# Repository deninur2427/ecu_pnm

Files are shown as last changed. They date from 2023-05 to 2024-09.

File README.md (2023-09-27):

# PNM Engine Control Planning

Custom Engine Control Unit for LPG

## Planning

- [X] Ngobrol Rencana

### Input

- [ ] Crankshaft Position Sensor
    - [ ] Pasang Gigi. Rencana Penempatan 12-1 Crank Tooth:
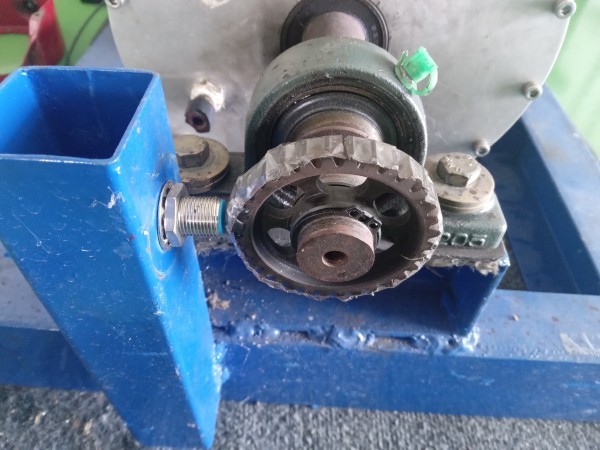
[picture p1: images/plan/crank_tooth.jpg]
images

    - [ ] Cetak Crank Teeth 12-1. Diameter Poros 22mm. Contoh:

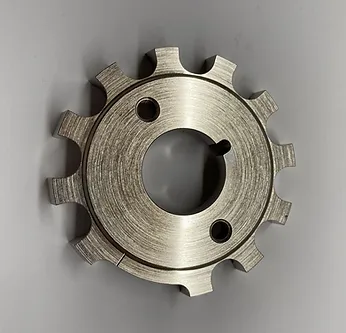
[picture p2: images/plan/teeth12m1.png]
images
    
    - [ ] Alternatif akrilik. Desain (tebal 2mm atau 3mm) untuk 24-1:

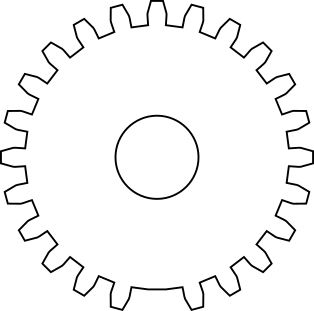
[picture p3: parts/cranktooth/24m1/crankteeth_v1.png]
    
    - [ ] Pasang Sensor Gigi. Rencana Sensor: Opto Interruptor: [Tokopedia](https://www.tokopedia.com/xurve-store/fc-03-ir-infrared-speed-kecepatan-sensor-photo-opto-interruptor)

- [ ] Trottle Position Sensor
    - [ ] Pemasangan. Dimana dekat mesin karena tidak terkoneksi dengan mekanik intake
    - [ ] Pembelian Sensor TPS: [Tokopedia](https://www.tokopedia.com/primacave/terbaru-sensor-tps-throttle-position-sensor-beat-fi-vario-125-thalland)

- [ ] Optimasi
    - [ ] Sensor Temperature (Tentative)
    - [ ] CO2 Sensor. Rencana [Tokopedia](https://www.tokopedia.com/amanahotopart/sensor-oxygen-honda-jazz-city-belakang-oksigen-co2-o2-copotan-asli-ori)

### Output

- [ ] Intake
    - [ ] Injector. Rencana [Tokopedia](https://www.tokopedia.com/sumahonda/injector-assy-fuel-pcx-150-k97-vario-150-esp-16450k59a11)
    - [ ] Pemasangan depan Inlet tanpa klep pengatur udara:
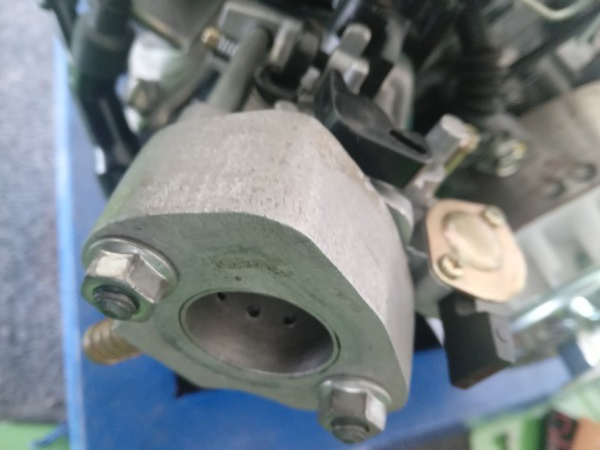
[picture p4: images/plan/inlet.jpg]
images


- [ ] Spark Plug
    - [ ] Coil. Rencana [Tokopedia](https://www.tokopedia.com/lestarimotor2/coil-koil-scoopy-esp-scoopy-fi-injeksi-30510-k16-a01-asli-ahm)
    - [ ] Cop Busi [Tokopedia](https://www.tokopedia.com/azkamotor99/canglong-tutup-cop-busi-grand-supra-x-x-125-legenda-revo-kharisma)
    - [ ] Plug telah tersedia
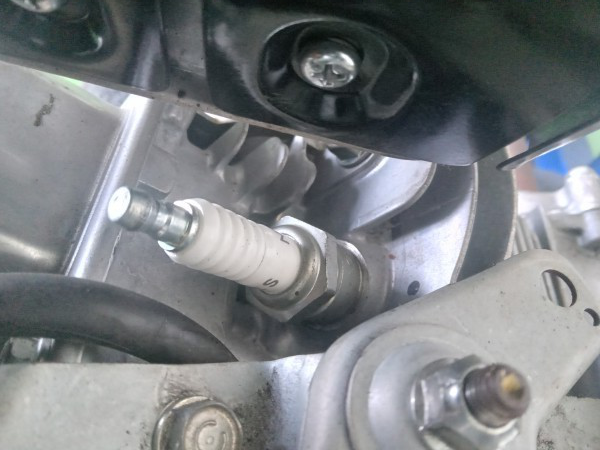
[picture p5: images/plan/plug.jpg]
images


- [ ] Aki. Alternator dan Kiprok tidak ada di Mesin
    - [x] Charger Aki tersedia
    - [ ] Jepit Aki dan Wiring nya

### PCB

- [ ] Drafting
    - [ ] Single Cylinder
        - [ ] Standalone PCB
        - [x] Nucleo Based
            - [x] F103RB
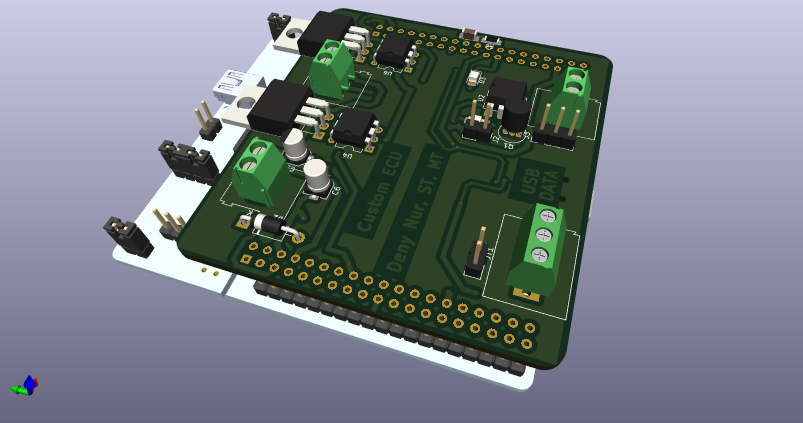
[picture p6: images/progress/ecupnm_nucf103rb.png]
images

- [x] Rencana Anggaran Total

### Update Kegiatan

- Tanggal 31 Juli 2023: [Catatan](https://github.com/deninur2427/ecu_pnm/blob/main/docs/notes/tes_31072023.md)
- Tanggal 24 Agustus 2023: [Catatan](https://github.com/deninur2427/ecu_pnm/blob/main/docs/notes/tes_24082023.md)
- Tanggal 19 September 2023: [Catatan](https://github.com/deninur2427/ecu_pnm/blob/main/docs/notes/tes_19092023.md)

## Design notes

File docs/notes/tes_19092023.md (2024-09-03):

# Catatan Kegiatan 19 September 2023

## Progress Kegiatan

### Hasil

Beberapa hasil yg didapat:
- Mesin sempat idle dalam waktu singkat namun tidak lanjut
- Timing pembakaran stabil namun terkadang masih terlambat
- Tidak ada gejala knocking

Klik gambar ini untuk memulai video

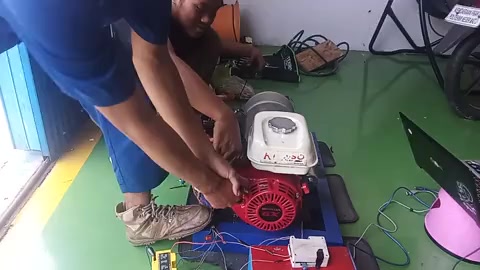
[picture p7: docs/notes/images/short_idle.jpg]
[](https://raw.githubusercontent.com/deninur2427/ecu_pnm/main/docs/notes/images/short_idle.mp4)

Perbaikan jaringan elektrikal dan koil ditukar.

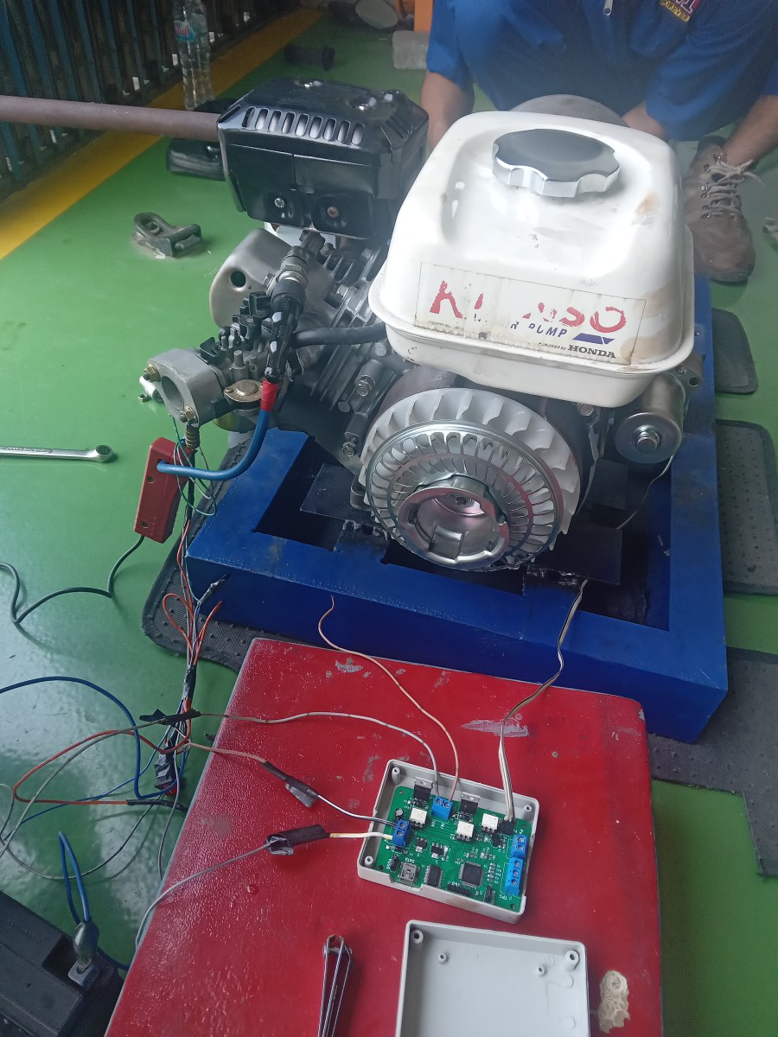
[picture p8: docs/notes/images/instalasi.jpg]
[]

### Catatan Perbaikan
- Pindah Crank-Teeth ke dekat block mesin untuk pembacaan lebih stabil

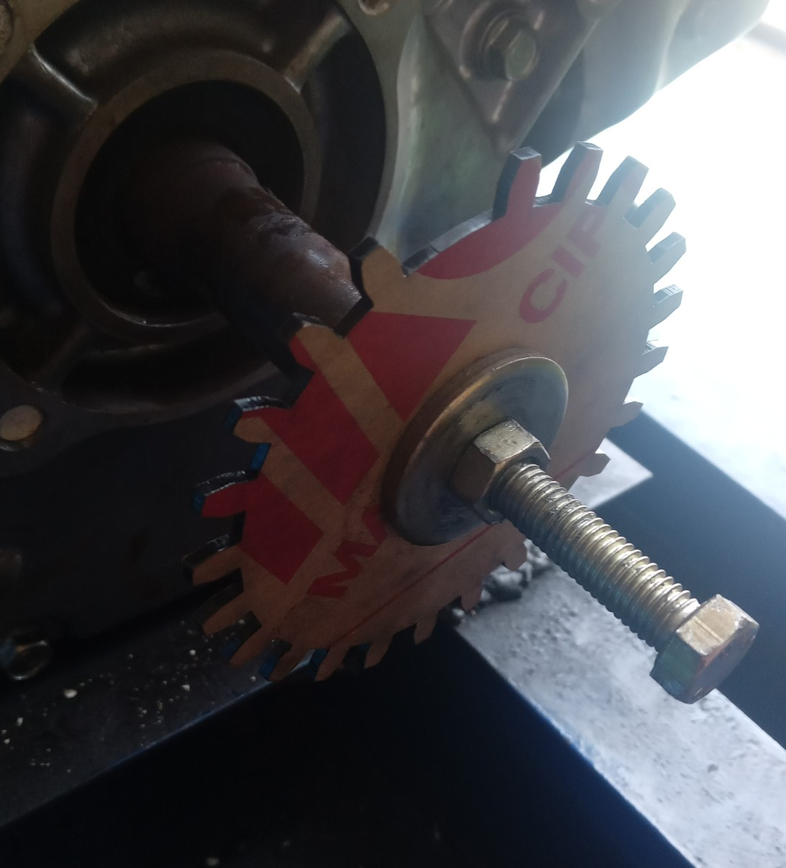
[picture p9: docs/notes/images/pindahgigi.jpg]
[]

- Update PCB sesuai catatan [berikut](https://github.com/deninur2427/ecu_pnm/blob/main/docs/notes/tes_24082023.md#update-pcb) dan mengecilkan ukuran

### Update PCB
- Regulator 5v ditambah opsi ke 7805
- Dioda FET pakai Schottky
- Dioda GND-GNDPWR pakai Schottky
- Serial-TTL ganti CH340C
- Wajib ada Capacitor Decouple dan Stabilizer
    + 100uF di 12V
    + 100uF di 5V
    + 100uF di 3v3
    + 0.1uF/100nF di 3v3 untuk Serial-TTL dan STM32

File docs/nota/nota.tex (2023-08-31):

\documentclass{article} % Definisi jenis dokumen

%%%%% Definisi paket-paket yang seharusnya digunakan %%%%%
\usepackage[utf8]{inputenc} % paket encoding input utf8
\usepackage[T1]{fontenc} % paket encoding huruf latin

%%%%% Definisi paket-paket yang digunakan sesuai kebutuhan %%%%%
\usepackage[yyyymmdd,hhmmss]{datetime} % paket tanggal-waktu
\usepackage{graphicx} % paket grafik/gambar
\usepackage[english]{babel} % paket modifikasi label/caption pada bahasa tertentu
\usepackage{geometry} % paket ukuran kertas dan margin
\usepackage{tabularray}
\usepackage{hyperref}
\usepackage{float}
\usepackage{caption}

%%%%% Pengaturan ukuran kertas dan margin %%%%%
\geometry{
	a4paper,
	left=10mm,
	right=10mm,
	top=15mm,
	bottom=15mm,
}

%%%%% Pengaturan perintah informasi perangkat lunak (hanya untuk GNU/Linux) %%%%%
\newcommand{\ShowOsVersion}{
	\immediate\write18{\unexpanded{foo=`uname -sro` && echo "${foo}" > tmp.tex}}
	\input{tmp}\immediate\write18{rm tmp.tex}
}

\newcommand{\ShowTexVersion}{
	\immediate\write18{\unexpanded{foo=`pdflatex -version | head -n1 | cut -d' ' -f1,2` && echo "${foo}" > tmp.tex}}
	\input{tmp}\immediate\write18{rm tmp.tex}
}

\begin{document}
%%%%%%%%%%%%%%%%%%%%%%%%%%%%%%%%%%%%%%%%%%%%%%%%%%%%%%%%%%%%%%%%%

	\begin{titlepage}

		\centering % untuk membuat tengah teks

		{
			\LARGE % pakai font besar
			\bf % pakai font BOLD
			Rekapitulasi Nota Kegiatan
		}

		\bigskip
		{\Large \bf Achmadi ST MT}
		\vfill % menambahkan ruang kosong vertikal

		\raggedright
		\noindent Buku ini ditulis dengan:\\ % tanda \\ menambahkan garis baru
		OS : \ShowOsVersion \\
		TeX : \ShowTexVersion \\
		Update: {\today} at \currenttime\\
	\end{titlepage}

	%%%%%%%%%%%%%%%%%%%%%%%%%%%%%%%%%%%%%%%%%%%%%%%%%%%%%%%%%%%%%%%%%

	\section{Tabel Rekapitulasi}
	
	\subsection{Transportasi}
	
	\begin{table}[H]
		\centering
		\begin{tabular}{|c|c|c|c|c|c|}
			\hline
			Items & Qty & Total & Shop & Paid & URL \\
			\hline
			Bus Kota & 6 & Rp. 30.000 & Bus-Suroboyo & Mas Deni & \hyperlink{https://tiketresmi.com/suroboyo-bus/}{Info-Traif} \\
			Bus Antar-Kota & 6 & Rp. 360.000 & Restu & 4/6 Mas Deni & - \\
			Penginapan & 1 & Rp. 150.000 & Red-Doorz & Mas Deni & - \\
			Penginapan & 1 & Rp. 198.000 & Red-Doorz & Mas Deni & - \\
			\hline
			\textbf{Total} & & Rp. 738.000 & - & - & - \\
			\hline
		\end{tabular}
	\end{table}

	\subsection{Prototype}

	\begin{table}[H]
	\centering
	\begin{tabular}{|c|c|c|c|c|c|}
		\hline
		Items & Qty & Total & Shop & Paid & URL \\
		\hline
		Opto-Encoder & 3 & Rp. 24.000 & Akhi-Shop Surabaya &  - & \hyperlink{https://www.tokopedia.com/akhishop/opto-coupler-encoder-sensor-module}{Tokopedia} \\
		Box-Plastic & 3 & Rp. 24.600 & Eltech Surabaya & - & \hyperlink{https://www.tokopedia.com/eltech-online/box-electronic-instrument-project-plastic-03-15-cream-40x84x142mm}{Tokopedia} \\
		Diode-Regulator & 12 & Rp. 5.100 & Mulsanne Surabaya & - & \hyperlink{https://www.tokopedia.com/mulsanne/ic-ams1117-5-volt-step-down-smd-800ma}{Tokopedia} \\
		Sabut Kawat & 1 & Rp. 7.200 & Alfamart Madiun & - & - \\
		Tang-Kabel, Komponen & - & Rp. 52.000 & Bintang-Mas Madiun & Mas Deni & - \\
		Komponen & - & Rp. 21.000 & Bintang-Mas Madiun & Mas Deni & - \\
		Komponen & - & Rp. 15.000 & Berkat Surabaya & - & - \\
		Komponen & - & Rp. 16.000 & Berkat Surabaya & - & - \\
		Komponen & - & Rp. 10.000 & Berkat Surabaya & - & - \\
		Komponen & - & Rp. 10.500 & Berkat Surabaya & - & - \\
		Komponen & - & Rp. 100.900 & Digiware Surabaya & - & \hyperlink{https://digiwarestore.com/id/}{Digiware} \\
		FT232RL & 2 & Rp. 102.100 & Digiware Surabaya & - & \hyperlink{https://digiwarestore.com/id/serial-communication/ft232rl-166019.html}{Digiware} \\
		Cap 0.1uF & 20 & Rp. 10.000 & Digiware Surabaya & - & \hyperlink{https://digiwarestore.com/id/smd-capacitor/01uf-50v-10-0805-t-241110.html}{Digiware} \\
		Potong Akrilik & 6 & Rp. 30.000 & Embong-Malang Surabaya & - & - \\
		PCB Versi 1 & 3 & Rp. 298.800 & Raftech & - & \hyperlink{https://www.tokopedia.com/raftech/jasa-cetak-pcb-double-layer-fr4-full-masking-jalur-masking-silkscreen}{Tokopedia} \\
		PCB Versi 2 & 3 & Rp. 371.300 & Gerai-Cerdas & - & \hyperlink{https://www.tokopedia.com/geraicerdas/cetak-pcb-1-keping-single-double-layer-rapid-prototyping-satuan}{Tokopedia} \\
		STM32F103RB & 4 & Rp. 180.000 & Shenzhen China & - & \hyperlink{https://id.aliexpress.com/item/1005002651134172.html}{Aliexpress} \\
		PCB Holder & 1 & Rp. 35.000 & Cellkit Surabaya & - & \hyperlink{https://www.tokopedia.com/cellkit/cellkit-penjepit-papan-pcb-single-per-pcb-holder}{Tokopedia} \\
		\hline
		\textbf{Total} & & Rp. 1.259.500 & - & - & - \\
		\hline
	\end{tabular}
	\end{table}

	\subsection{Konsumsi}
	
	\begin{table}[H]
		\centering
		\begin{tabular}{|c|c|c|c|c|c|}
			\hline
			Items & Qty & Total & Shop & Paid & URL \\
			\hline
			Roti Gembul & 2 & Rp. 37.000 & Gembul Madiun & Mas Deni & - \\
			Telur & 10 & Rp. 24.000 & Alfamart & - & - \\
			Telur & 6 & Rp. 21.000 & Alfmart & - & - \\
			\hline
			\textbf{Total} & & Rp. 82.000 & - & - & - \\
			\hline
		\end{tabular}
	\end{table}

	\newpage
	\section{Scan Nota}

	\begin{figure}[H]
		\centering
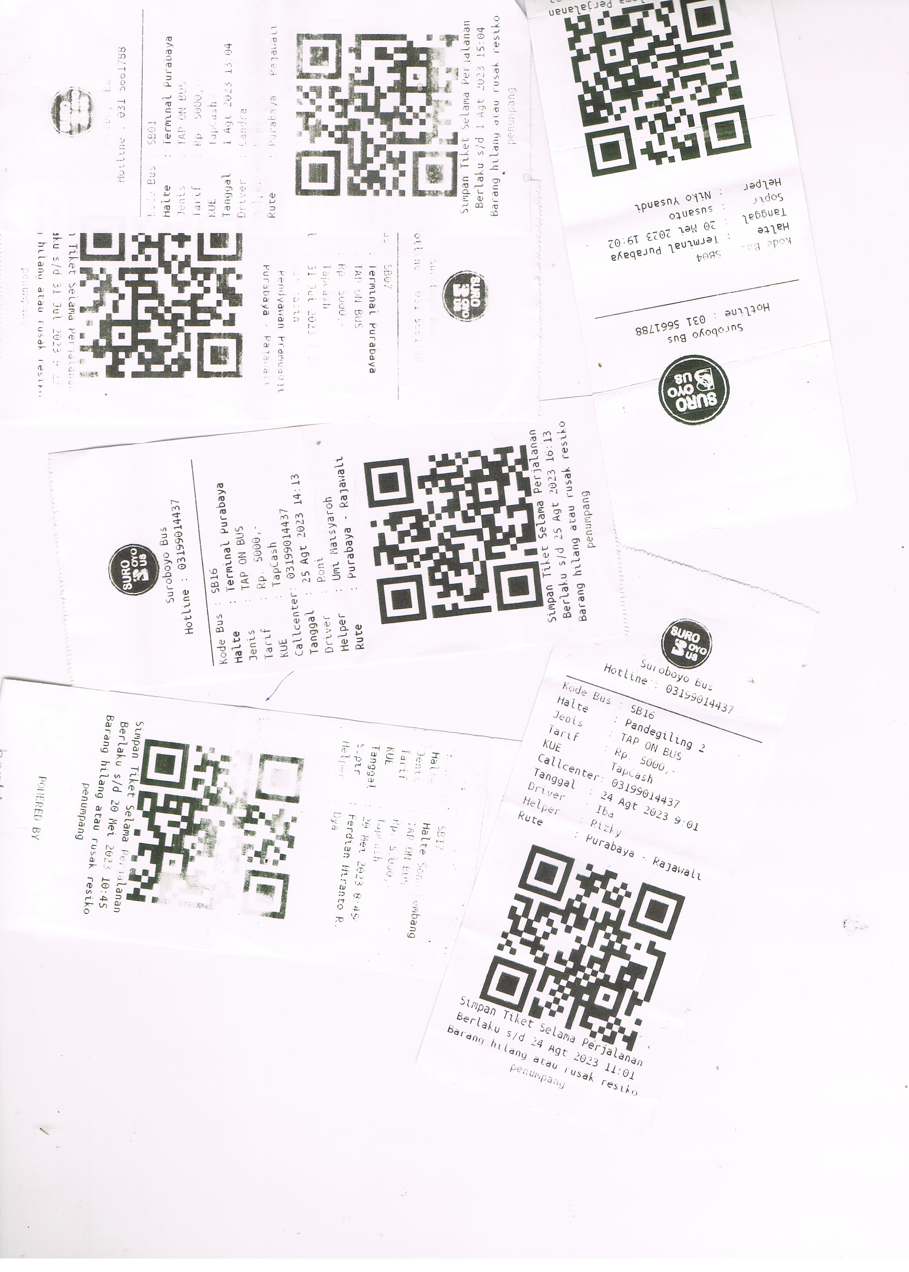
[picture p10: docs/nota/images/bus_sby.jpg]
		
	\end{figure}

	\begin{figure}[H]
		\centering
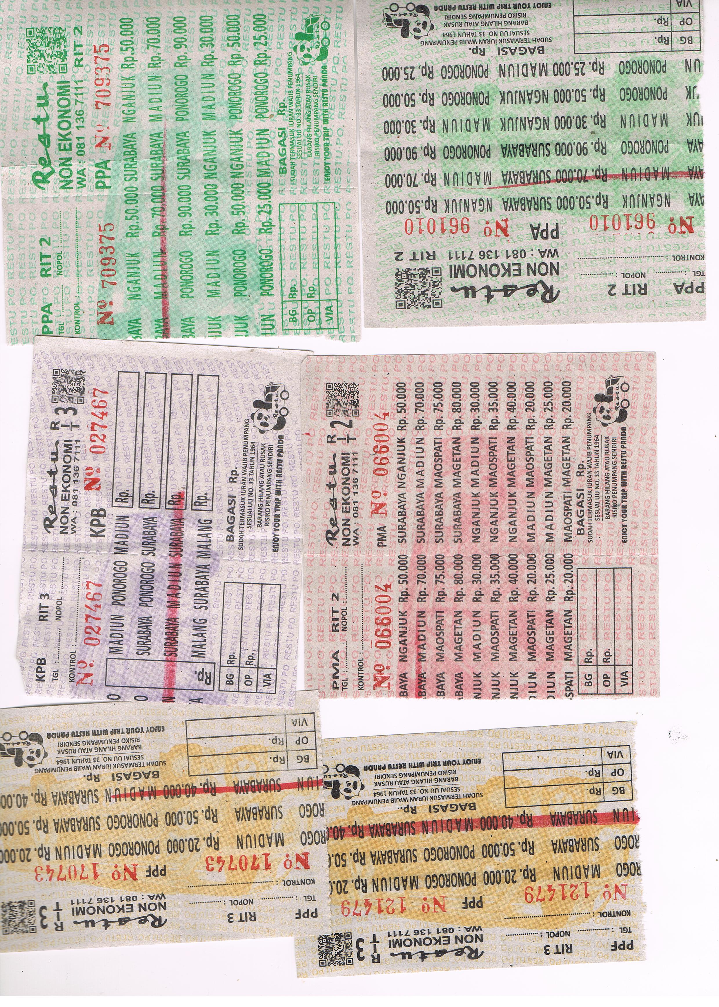
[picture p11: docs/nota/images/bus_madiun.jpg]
		
	\end{figure}

	\begin{figure}[H]
		\centering
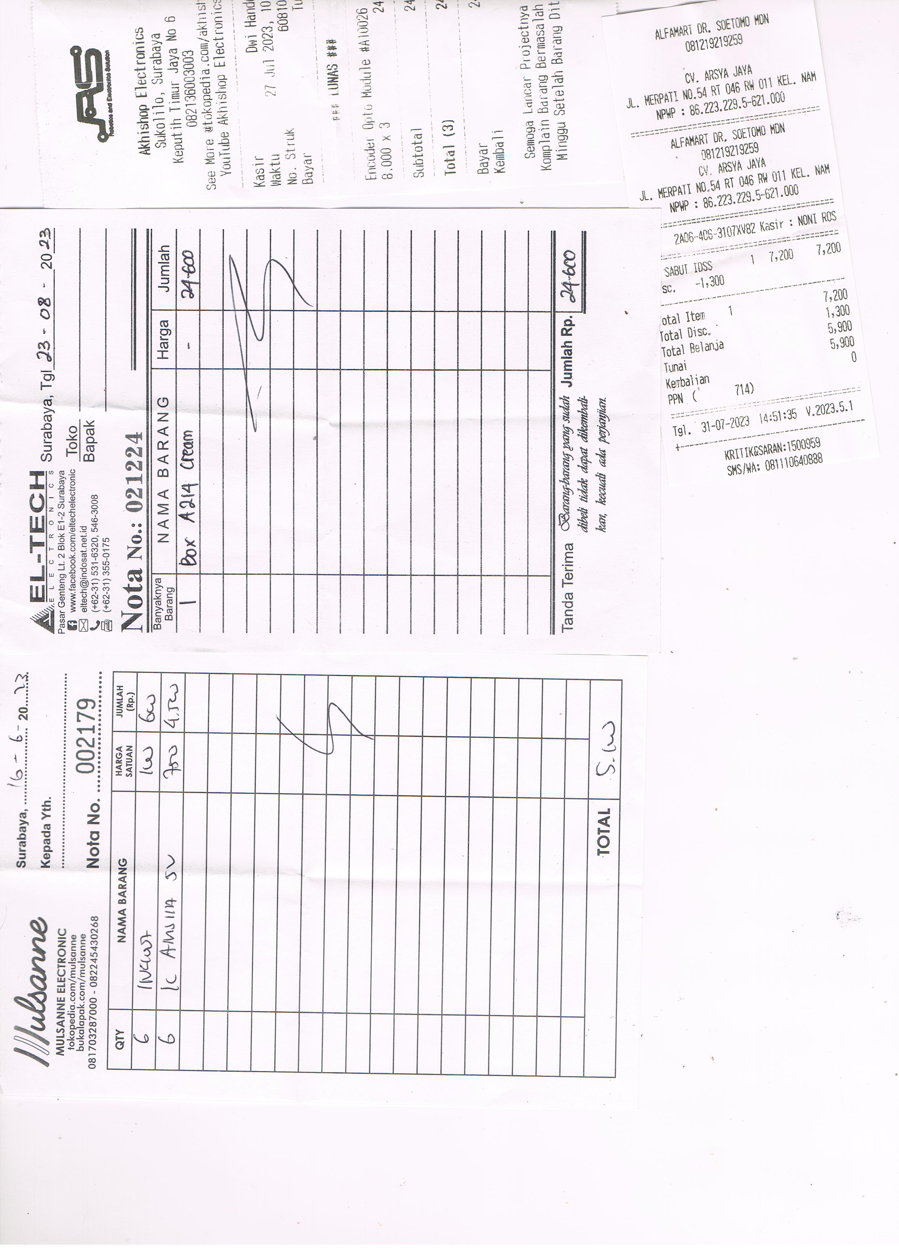
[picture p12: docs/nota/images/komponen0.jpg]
		
	\end{figure}

	\begin{figure}[H]
		\centering
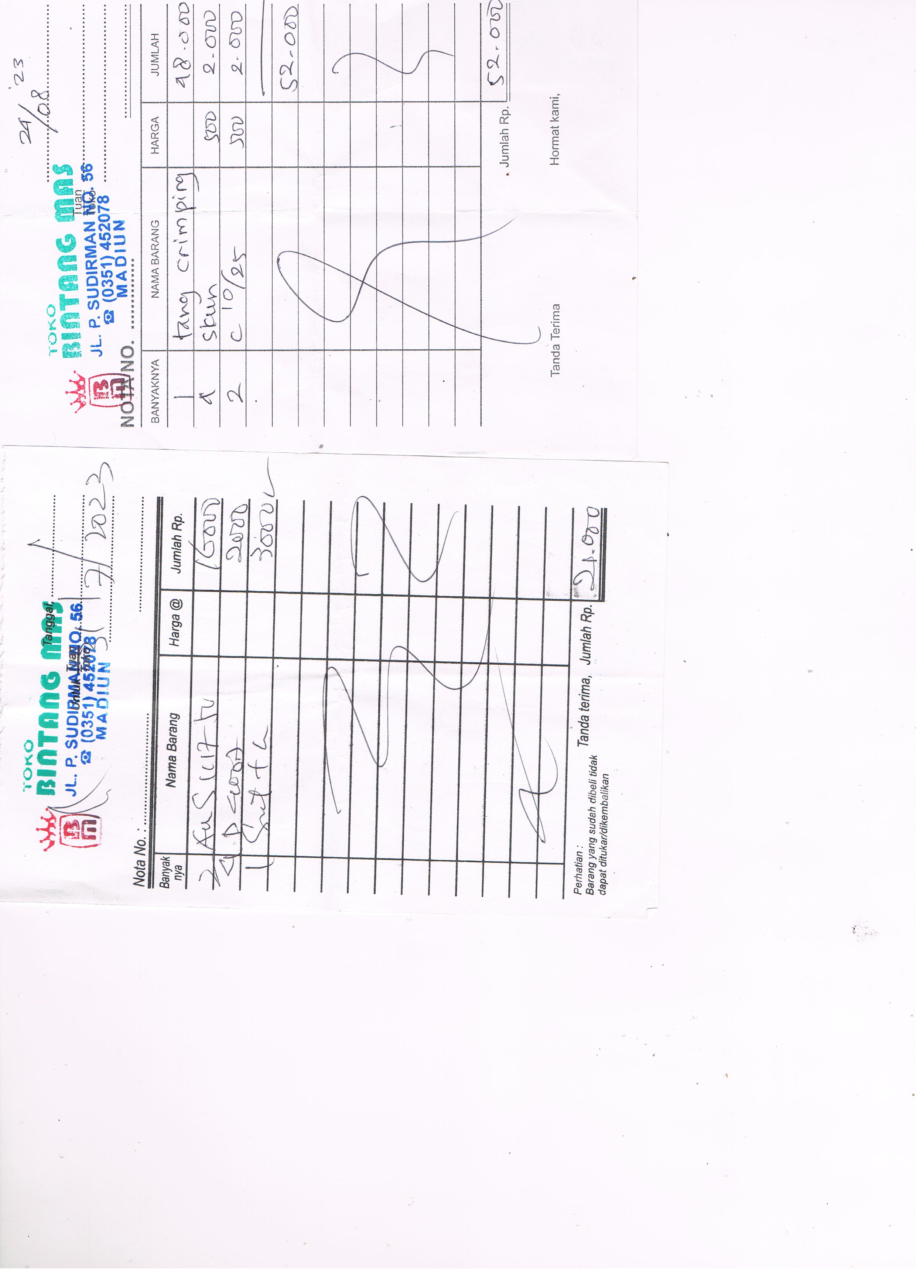
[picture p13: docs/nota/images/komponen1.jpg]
		
	\end{figure}

	\begin{figure}[H]
		\centering
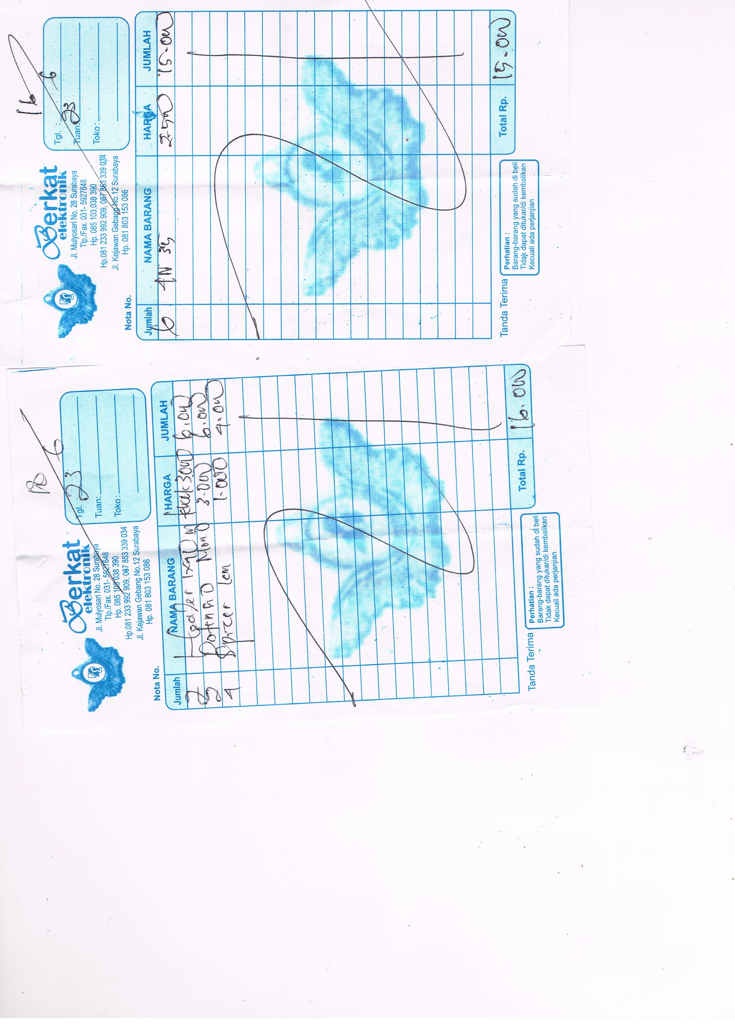
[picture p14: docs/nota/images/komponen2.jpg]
		
	\end{figure}

	\begin{figure}[H]
		\centering
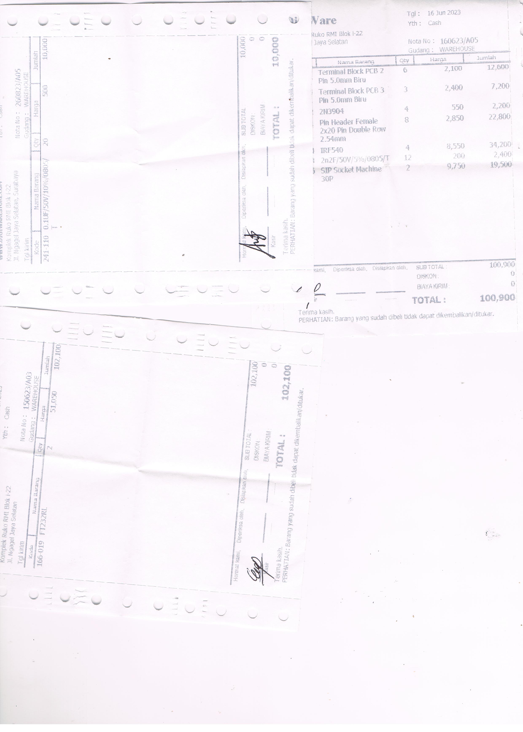
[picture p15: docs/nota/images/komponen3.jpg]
		
	\end{figure}

	\begin{figure}[H]
		\centering
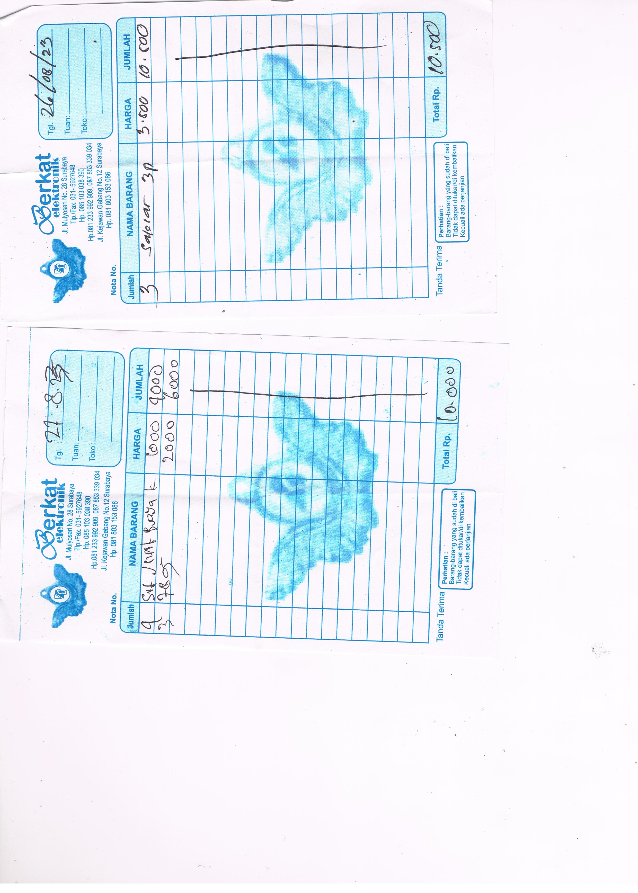
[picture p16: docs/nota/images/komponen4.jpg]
		
	\end{figure}

	\begin{figure}[H]
		\centering
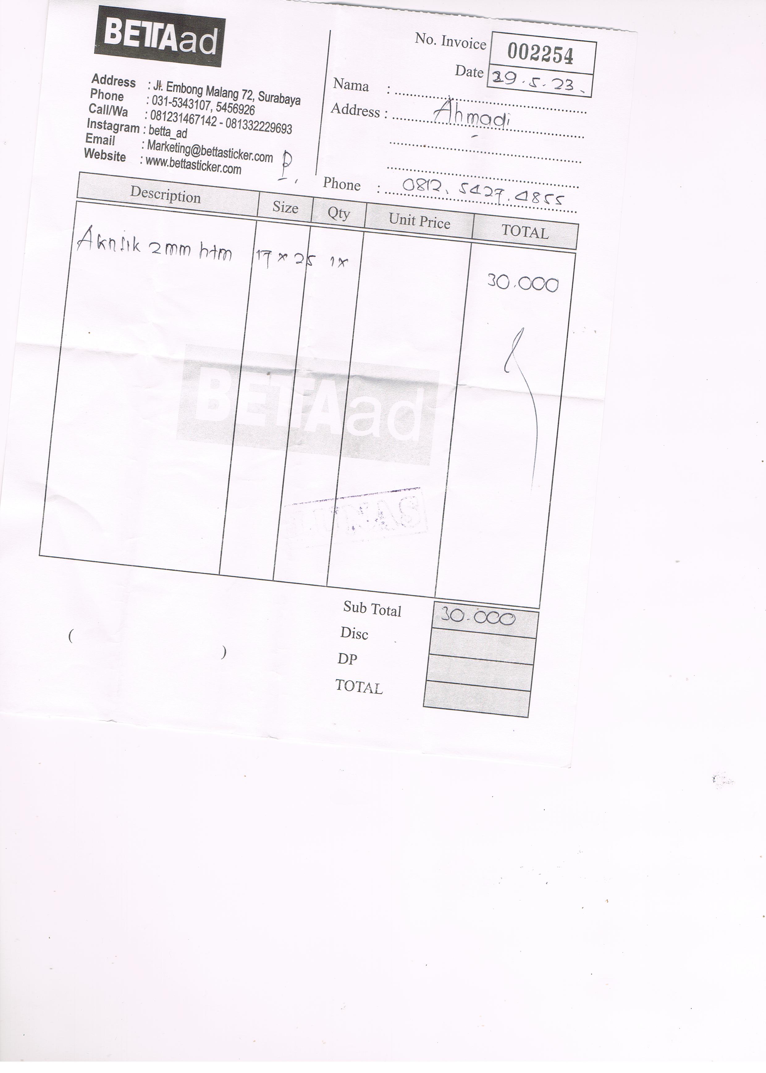
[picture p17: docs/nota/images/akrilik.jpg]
		
	\end{figure}

	\begin{figure}[H]
		\centering
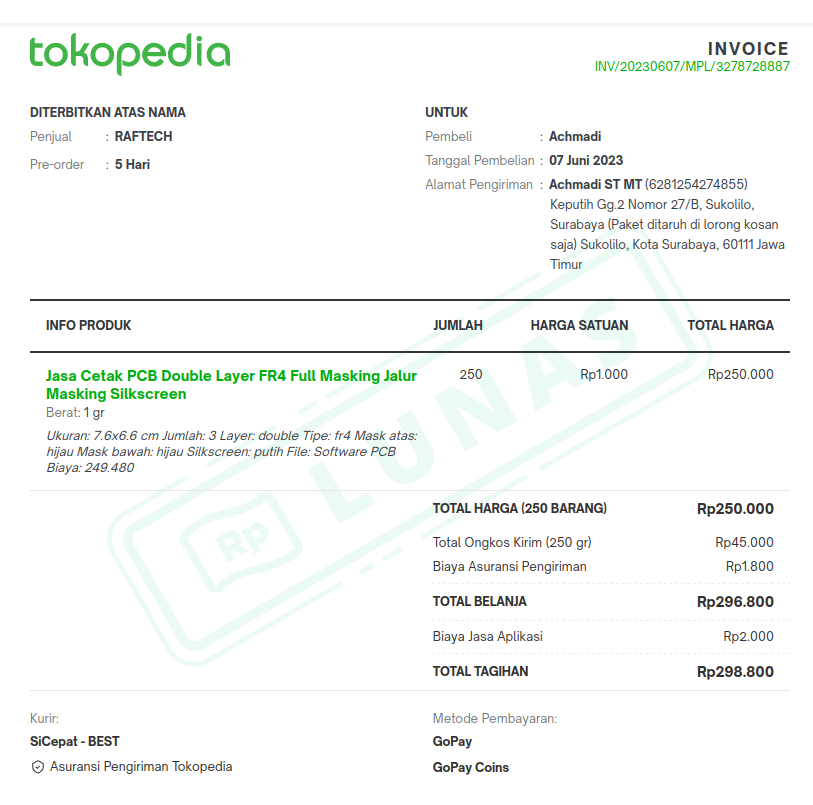
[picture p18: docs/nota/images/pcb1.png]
		
	\end{figure}

	\begin{figure}[H]
		\centering
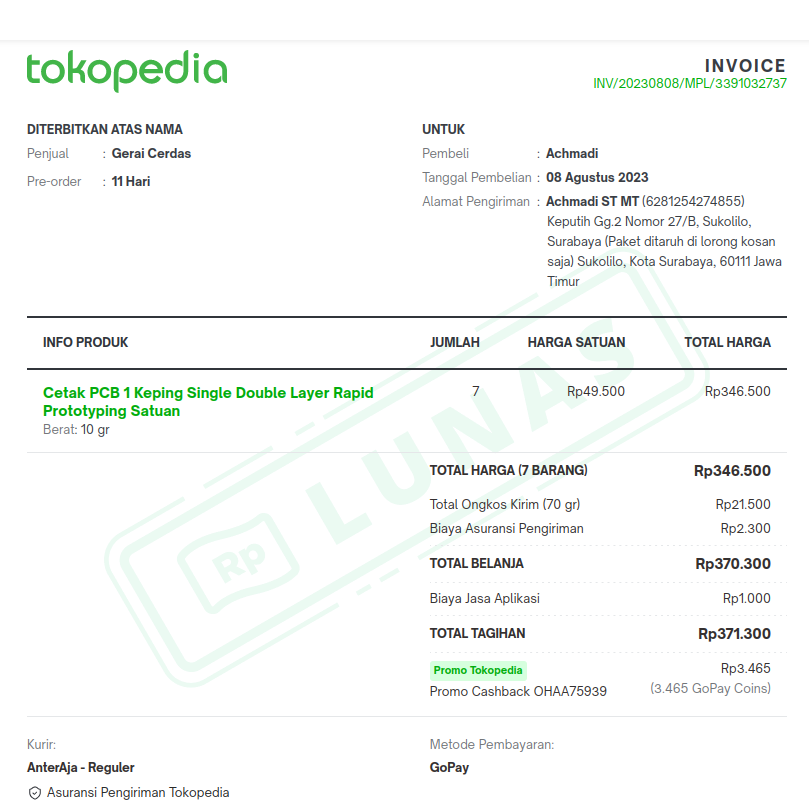
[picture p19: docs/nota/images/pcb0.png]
		
	\end{figure}
	
	\begin{figure}[H]
		\centering
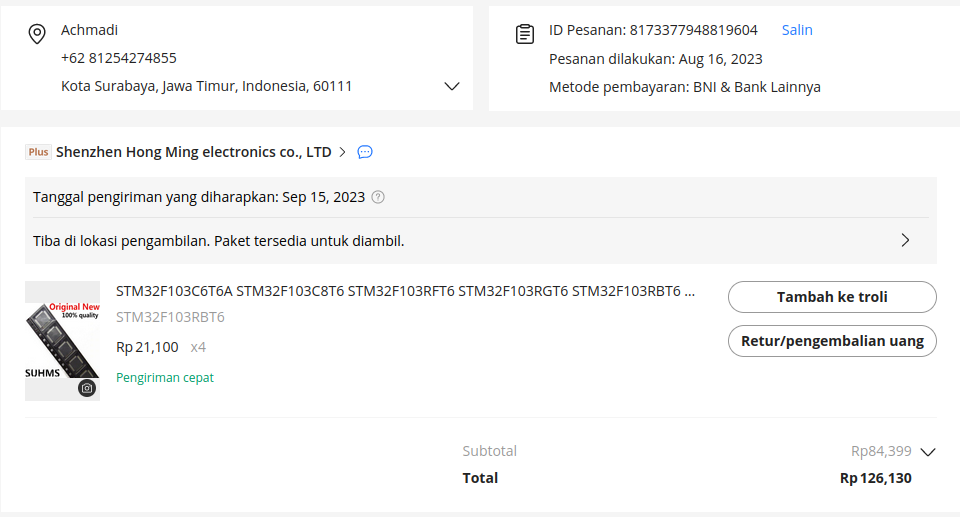
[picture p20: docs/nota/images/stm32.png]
		
	\end{figure}

	\begin{figure}[H]
		\centering
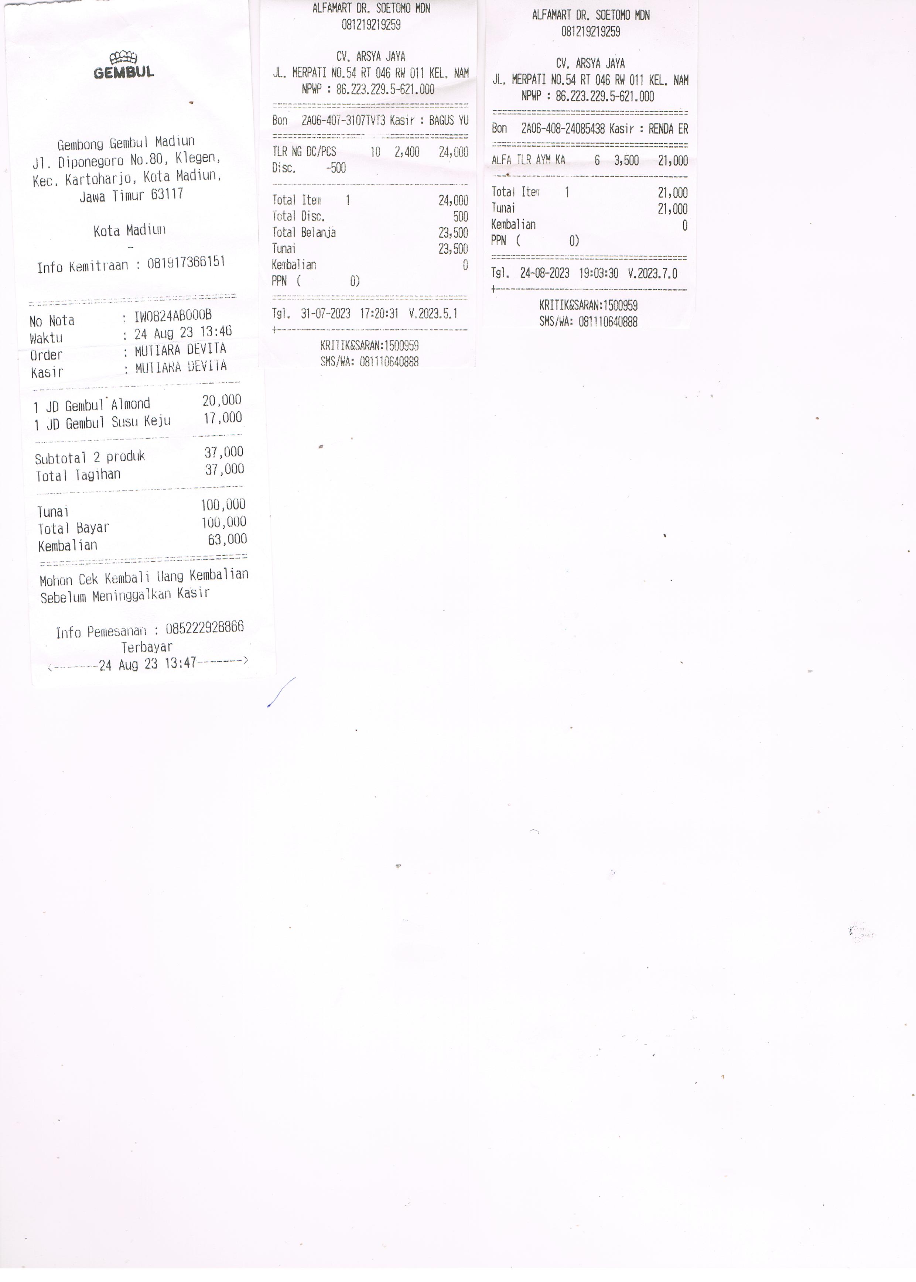
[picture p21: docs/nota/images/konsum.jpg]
		
	\end{figure}

	\begin{figure}[H]
		\centering
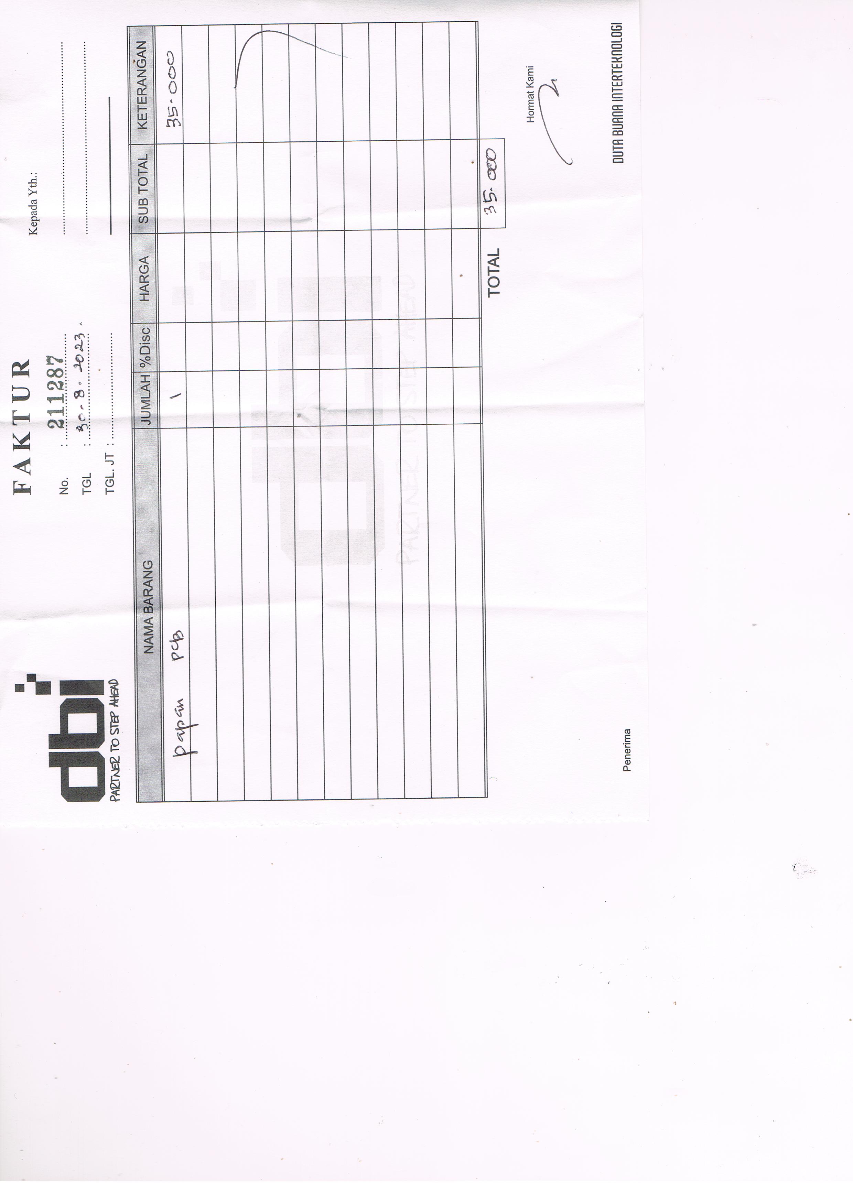
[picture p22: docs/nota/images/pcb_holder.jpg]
		
	\end{figure}

\end{document}

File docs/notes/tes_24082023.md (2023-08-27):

# Catatan Kegiatan 24 Agustus 2023

## Progress Kegiatan

### Perakitan

Merapikan wiring dan posisi coil

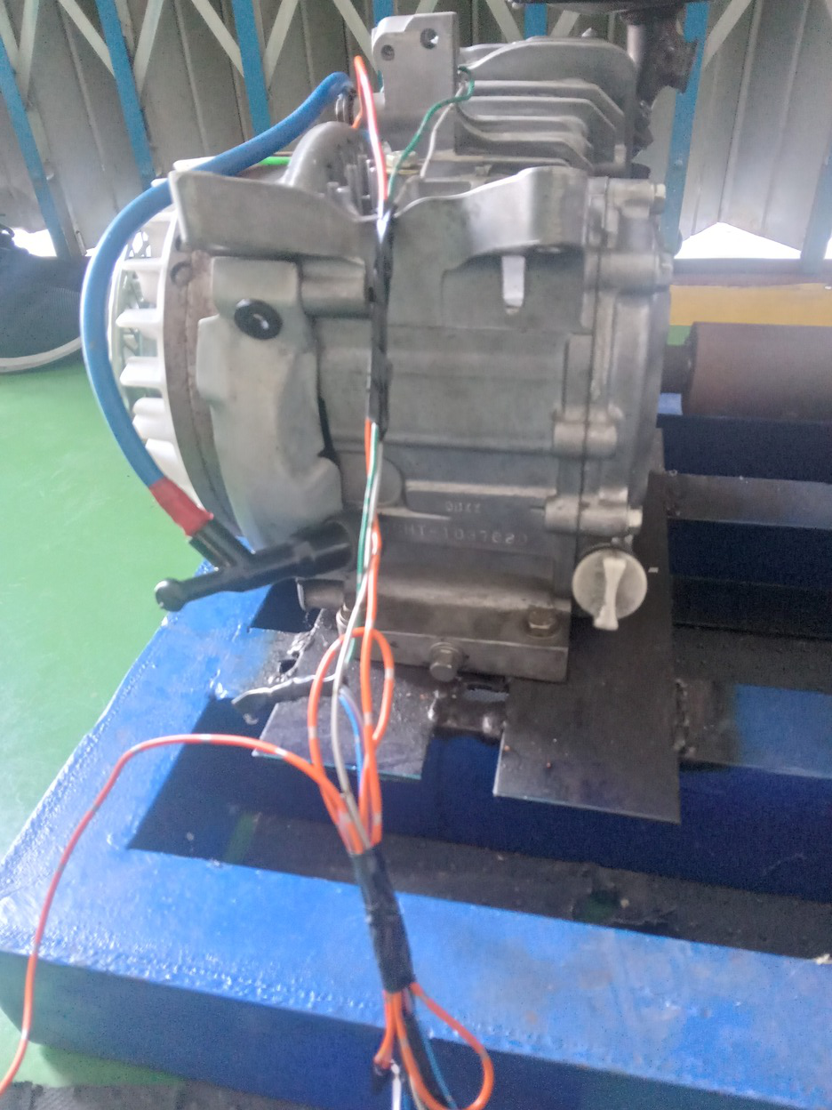
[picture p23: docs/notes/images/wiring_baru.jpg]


Kemudian instal prototipe ECU baru

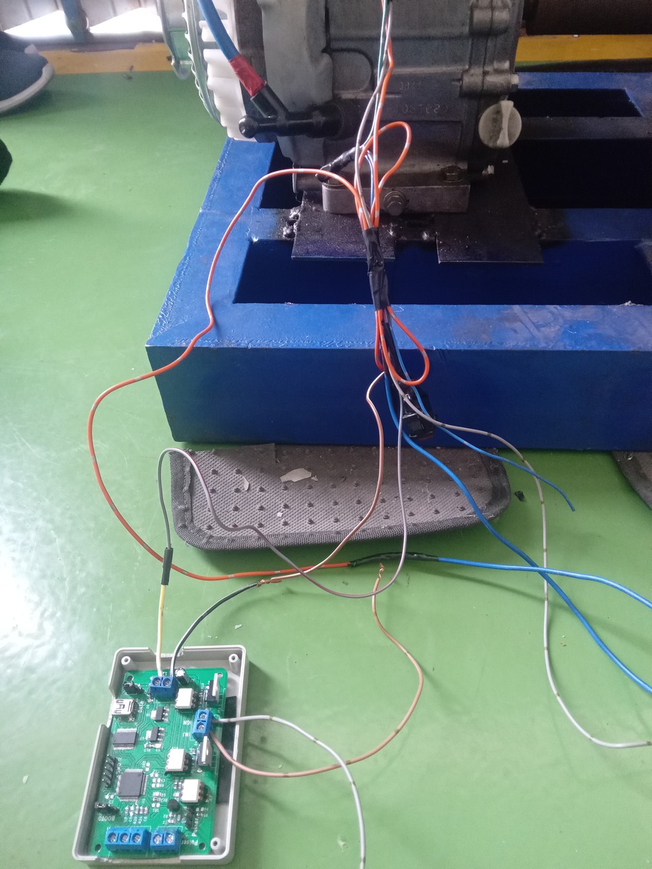
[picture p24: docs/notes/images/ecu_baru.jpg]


### Kendala

#### Coil Unstable

Coil memercik terus menerus.
Menyebabkan chip FTDI mati.

Dikurangi menggunakan Elco 10uF/25V

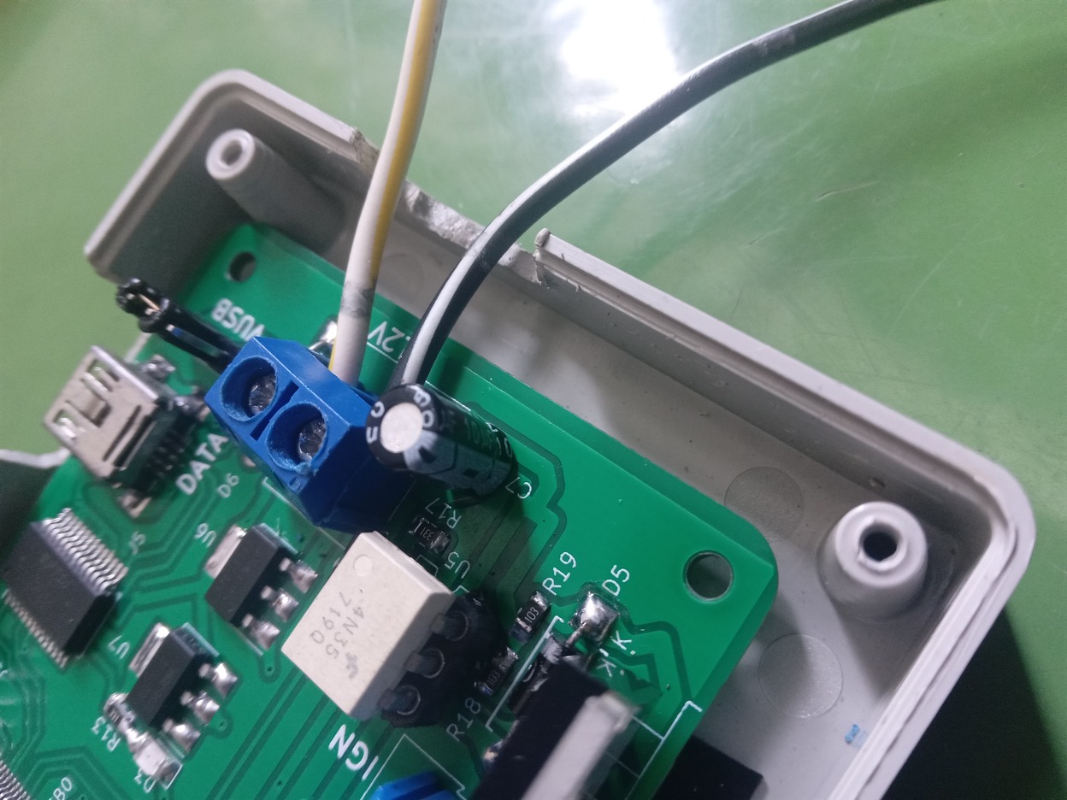
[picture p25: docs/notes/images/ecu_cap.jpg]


#### Engine Unstarted

Engine masih knocking

## Improvisasi

### Metode Tes

Pakai Ignition Timing Light Test

### Update PCB
- Regulator 5v ditambah opsi ke 7805
- Serial-TTL ganti CH340C
- Wajib ada Capacitor Decouple dan Stabilizer
    + 100uF di 12V
    + 0.1uF/100nF di 3v3 untuk Serial-TTL dan STM32

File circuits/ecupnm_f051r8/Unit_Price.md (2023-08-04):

# Local Indonesia Price Unit

| Komponen | QTY x Satuan | URL | Catatan |
|:---:|:---:|:---:|:---:|
| IC 4N35 | Rp. 10.000 | [Tokopedia](https://www.tokopedia.com/jevonelektronik/ic-4n35-optocoupler-original) | - |
| STM32F051R8T6 | Rp. 80.000 | [Aliexpress](https://id.aliexpress.com/item/1005004923074652.html) | Masih Stock |
| AMS1117 5v | Rp. 2.000 | [Tokopedia](https://www.tokopedia.com/cosmic-iot/ams1117-5v-ams-1117-5-volt-smd-sot-223-sot223) | - |
| AMS1117 3v | Rp. 2.000 | [Tokopedia](https://www.tokopedia.com/mri/ams1117-3-3v-smd-regulator-sot-223) | - |
| H11L1 | Rp. 7.000 | [Tokopedia](https://www.tokopedia.com/eltech-online/h11l1-h-11l1-h11-l1-optocoupler) | - |
| FT232RL | Rp. 65.000 | [Tokopedia](https://www.tokopedia.com/eltech-online/ft232rl-ft-232rl-232-ftdi-usb-to-serial-uart-rs-232-rs232-rs) | - |
| IRF540 | Rp. 22.000 | [Tokopedia](https://www.tokopedia.com/eltech-online/ft232rl-ft-232rl-232-ftdi-usb-to-serial-uart-rs-232-rs232-rs) | - |
| 2N3904 | Rp. 1.200 | [Tokopedia](https://www.tokopedia.com/isee/2n-3904-2n3904-dip-transistor-to-92-0-2a-40v) | - |
| PCB Prototyping | Rp. 150.000 | [Tokopedia](https://www.tokopedia.com/geraicerdas/cetak-pcb-1-keping-single-double-layer-rapid-prototyping-satuan) | Estimasi Total Luasan PCB |
| Non-IC | Rp. 50.000 | - | Gelondongan Komponen |
| Ongkir/Transport | Rp. 50.000 | - | - |
| Jasa Solder/Assembly Manual | Rp. 150.000 | - | Termasuk Checking PCB |

Total Estimasi Per Unit Rp. 587.200

Belum Termasuk:
- Jasa Programming Firmware
- Jasa Programming Interfacing

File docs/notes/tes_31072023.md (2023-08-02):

# Catatan Kegiatan 31 Juli 2023

## Progress Kegiatan

### Perakitan:

#### Encoder

PickUp encoder untuk posisi Crankshaft telah terpasang.

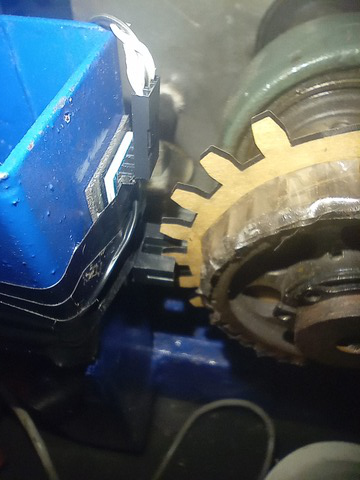
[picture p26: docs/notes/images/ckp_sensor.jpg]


**Catatan:** Perhitungan nomor gigi perlu dicek ulang

#### Wiring Coil

Konfigurasi Wiring:
- 0V di tulang coil
- Signal di pin dekat kabel busi
- 12V di pin yang tersisa
    
**Catatan:** Coil sudah dapat memantik
    
#### Wiring Injector

Konfigurasi Wiring:
- 12V di kabel merah
- Signal di kabel hitam
    
#### Wiring Overall

Dokumentasi hasil Wiring dan pemasangan Sakelar:

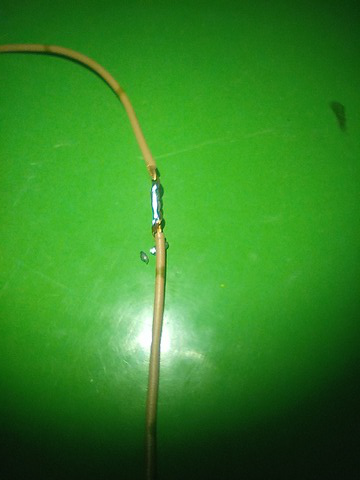
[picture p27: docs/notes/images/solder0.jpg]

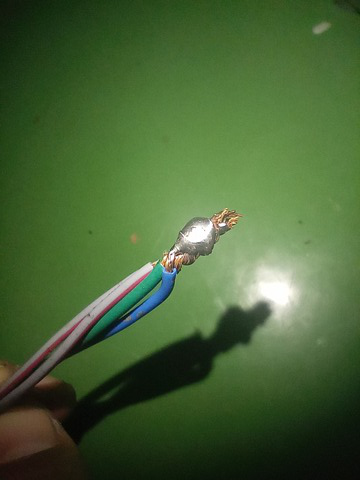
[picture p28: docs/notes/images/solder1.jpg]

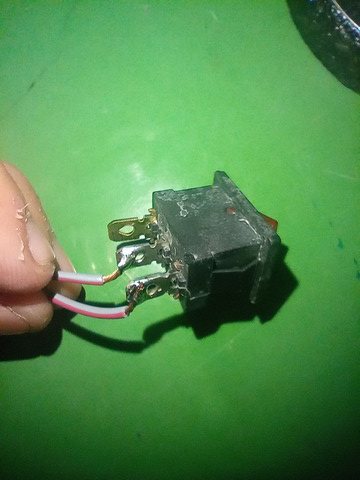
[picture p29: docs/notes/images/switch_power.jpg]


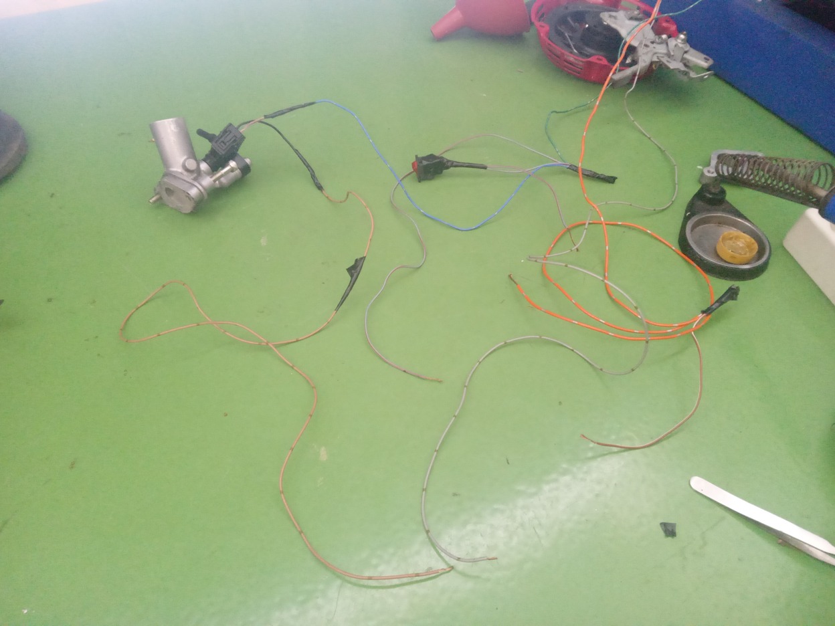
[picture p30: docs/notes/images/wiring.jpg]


### Masalah

Tegangan Induksi Balik dari Coil menyebabkan:

- Regulator 3.3 Volt terbakar:



- Chip STM32 mengalami kerusakan di internal flash memory sehingga ukuran memory mengecil dan tidak dapat "mass erase":





### Penanganan Masalah

- Pemasangan Diode Proteksi Induksi



- Ganti Chip STM32

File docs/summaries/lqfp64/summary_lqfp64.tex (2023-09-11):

\documentclass[a4paper,12pt,oneside,pdflatex,italian,final,twocolumn]{article}

\usepackage[utf8]{inputenc}
\usepackage{parallel}
\usepackage{siunitx}
\usepackage{booktabs}
\usepackage{fancyhdr}
\usepackage{subcaption}
\usepackage{minted}
\usepackage{hyperref}
\usepackage{pdfpages}

\usepackage[export]{adjustbox}
\usepackage[margin=0.5in]{geometry}
\addtolength{\topmargin}{0in}

\usepackage{libertine}
\renewcommand*\familydefault{\sfdefault}  %% Only if the base font of the document is to be sans serif
\usepackage[T1]{fontenc}

\hypersetup{
	colorlinks=true, %set true if you want colored links
	linktoc=all,     %set to all if you want both sections and subsections linked
	linkcolor=blue,  %choose some color if you want links to stand out
	urlcolor=blue,   %url color
}

\definecolor{LightGray}{gray}{0.95}

\title{Custom Single Cylinder ECU}
\author{Achmadi ST MT}
\date{September 2023}

\begin{document}
	\pagestyle{fancy}

	\lhead{DeniNur/Achmadi}
	\chead{\today}
	\rhead{Specification Document}

	\onecolumn
	\begin{figure}

	\end{figure}\begin{minipage}{0.47\textwidth}
		\centering

	\end{minipage}
	\hfill
	\begin{minipage}{0.47\textwidth}
		\raggedleft
		\Huge \textbf{Custom Single Cylinder ECU v1}
	\end{minipage}

	\begin{figure}
		\begin{minipage}{0.47\textwidth}

			\section{Overview}
			\begin{itemize}
				\item Minimal and Flexible Engine Control Unit
				\item Reading TPS and RPM with calibration capability
				\item Control Injection and Ignition
				\item Serial Data Interface in Real-time
				\item Designed to easy of use for general Injection engines
				\item Build as single circuit board with minimal setup
				\item Based on STM32Fx series that popular in automotive industries
			\end{itemize}

		\end{minipage}
		\hfill
		\begin{minipage}{0.47\textwidth}
			\centering
			
		\end{minipage}
	\end{figure}

	\raggedright

	\section{Repository URLs}

	\begin{itemize}
		\item PCB Design: \url{https://github.com/deninur2427/ecu_pnm/tree/main/circuits/ecupnm_f051r8}

		\item Firmware: \url{https://github.com/deninur2427/ecu_pnm/tree/main/firmware/}

		\item Interface: \url{https://github.com/deninur2427/ecu_pnm/tree/main/interface/ecu_view/}

		\item Overall Repository: \url{https://github.com/deninur2427/ecu_pnm/}
	\end{itemize}

	\section{Technical specification}
	\centering
	\begin{tabular}{lcr}
		\toprule
		Parts & Unit & Value \\
		\midrule
		Power voltage & $V$ & 12 \\
		Main Chip & & STM32Fx LQFP64 \\
		Storage & & Internal EEPROM \\
		USB  Data Interface & & USB-Serial FT232RL \\
		Engine Control Transistor & & IRF540N \\
		TPS Input & & 12-bit ADC \\
		PULSER Input & & Any pulsed signals \\
		\bottomrule
	\end{tabular}

	\raggedright

	\newpage
	\section{Unit Preview}

	\begin{figure}[h]
		\centering
		\begin{subfigure}{0.45\textwidth}
			
			\caption{Mockup}
		\end{subfigure}
		\begin{subfigure}{0.45\textwidth}
			
			\caption{Actual}
		\end{subfigure}
	\end{figure}

	\section{Electrical Wiring}

	\begin{figure}[h]
		\centering
		
		\caption{Electrical Wiring}
	\end{figure}

	\section{Schematic Design}

	\includepdf[pages=-,angle=-90]{images/ecupnm_sch.pdf}

	\newpage
	\section{Firmware Summary}

	In Summary:
	\begin{itemize}
		\item Library Framework: ChibiOS/RT

		\item Running Mode: Real-Time Operating System

		\item Compiler target: GCC ARM with Newlib for STM32 LQFP64 chip-series.
	\end{itemize}

	Some code snippet from \href[]{https://github.com/deninur2427/ecu_pnm/blob/main/firmware/ecu/main.c}{main.c}:

	\begin{minted}[frame=lines,framesep=2mm,fontsize=\normalsize,bgcolor=LightGray]{c}
int main(void) {
	halInit();
	chSysInit();

	ecu_MEM_Init();
	ecu_GPIO_Init();
	ecu_SHELL_Init();
	ecu_ICU_Init();
	ecu_ADC_Init();
	ecu_GPT_Init();

	while (true) {
		ecu_SHELL_Loop();
		chThdSleepMilliseconds(500);
	}
}
	\end{minted}

	\section{Development Progress and Notes}

	List of Development Notes:
	\begin{itemize}
		\item \href{https://github.com/deninur2427/ecu_pnm/blob/main/docs/notes/tes_31072023.md}{July 31\textsuperscript{st}, 2023}

		\item \href{https://github.com/deninur2427/ecu_pnm/blob/main/docs/notes/tes_24082023.md}{August 24\textsuperscript{th}, 2023}
	\end{itemize}

\end{document}

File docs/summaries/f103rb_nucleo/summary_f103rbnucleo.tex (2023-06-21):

\documentclass[a4paper,12pt,oneside,pdflatex,italian,final,twocolumn]{article}

\usepackage[utf8]{inputenc}
\usepackage{parallel}
\usepackage{siunitx}
\usepackage{booktabs}
\usepackage{fancyhdr}
\usepackage{subcaption}
\usepackage{minted}
\usepackage{hyperref}
\usepackage{pdfpages}

\usepackage[export]{adjustbox}
\usepackage[margin=0.5in]{geometry}
\addtolength{\topmargin}{0in}

\usepackage{libertine}
\renewcommand*\familydefault{\sfdefault}  %% Only if the base font of the document is to be sans serif
\usepackage[T1]{fontenc}

\hypersetup{
	colorlinks=true, %set true if you want colored links
	linktoc=all,     %set to all if you want both sections and subsections linked
	linkcolor=blue,  %choose some color if you want links to stand out
	urlcolor=blue,   %url color
}

\definecolor{LightGray}{gray}{0.95}

\title{Custom Minimum ECU}
\author{Achmadi ST MT}
\date{June 2023}

\begin{document}
	\pagestyle{fancy}
	
	\lhead{Achmadi}
	\chead{\today}
	\rhead{Specification Document}
	
	\onecolumn
	
	\begin{figure}
		
	\end{figure}\begin{minipage}{0.47\textwidth}
		\centering
		
	\end{minipage}
	\hfill
	\begin{minipage}{0.47\textwidth}
		\raggedleft
		\Huge \textbf{Custom Minimum ECU v0.1}
	\end{minipage}

	\begin{figure}
		\begin{minipage}{0.47\textwidth}
			
			\section{Overview}
			\begin{itemize}
				\item Minimal and Flexible Engine Control Unit
				\item Reading TPS and RPM with calibration capability
				\item Control Injection and Ignition 
				\item Serial Data Interface in Real-time
				\item Designed to easy of use for general Injection engines
				\item Build as shield board top ST-Nucleo64 with STM32F103RBT6 chip
			\end{itemize}
			
		\end{minipage}
		\hfill
		\begin{minipage}{0.47\textwidth}
			\centering
			
			
		\end{minipage}
	\end{figure}

	\raggedright

	\section{Repository URLs}
	
	\begin{itemize}
		\item PCB Design: \url{https://github.com/deninur2427/ecu_pnm/tree/main/circuits/ecupnm_nucf103rb/}
		
		\item Firmware: \url{https://github.com/deninur2427/ecu_pnm/tree/main/firmware/}
		
		\item Interface: \url{https://github.com/deninur2427/ecu_pnm/tree/main/interface/ecu_view/}
		
		\item Overall Repository: \url{https://github.com/deninur2427/ecu_pnm/}
	\end{itemize}

	\section{Technical specification}
	\centering
	\begin{tabular}{lcr}
		\toprule
		Parts & Unit & Value \\
		\midrule
		Power voltage & $V$ & 12 \\
		Dimensions & $mm*mm*mm$ & xx*yy*zz (without cable) \\
		Weight & $g$ & x \\
		Main Chip & & STM32F103RBT6 \\
		Storage & & Internal EEPROM \\
		USB  Data Interface & & USB-Serial FT232RL \\
		Engine Control Transistor & & IRF540N \\
		TPS Input & & 12-bit ADC \\
		PULSER Input & & Any pulsed signals \\
		\bottomrule
	\end{tabular}
	
	\raggedright
	
	\newpage
	\section{Unit Preview}
	
	\subsection{Shield Bottom}
	
	\begin{figure}[h]
		\centering
		\begin{subfigure}[b]{0.32\textwidth}
			
			\caption{Mockup}
		\end{subfigure}
		~
		\begin{subfigure}[b]{0.32\textwidth}
			
			\caption{Actual}
		\end{subfigure}
	\end{figure}

	\subsection{Top Bottom}
	
	\begin{figure}[h]
		\centering
		\begin{subfigure}[b]{0.32\textwidth}
			
			\caption{Mockup}
		\end{subfigure}
		~
		\begin{subfigure}[b]{0.32\textwidth}
			
			\caption{Actual}
		\end{subfigure}
	\end{figure}

	\subsection{Assembled Unit}
	
	\begin{figure}[h]
		\centering
		\begin{subfigure}[b]{0.32\textwidth}
			
			\caption{Unit Top}
		\end{subfigure}
		~
		\begin{subfigure}[b]{0.32\textwidth}
			
			\caption{Unit Bottom}
		\end{subfigure}
	\end{figure}

	\section{Schematic Design}
	
	\includepdf[pages=-,angle=-90]{images/ecupnm_nucf103rb.pdf}
	
	\newpage
	\section{Firmware Summary}
	
	In Summary:
	\begin{itemize}
		\item Library Framework: ChibiOS/RT
		
		\item Running Mode: Real-Time Operating System
		
		\item Compiler target: GCC ARM with Newlib 
	\end{itemize}
	
	Some code snippet from \href[]{https://github.com/deninur2427/ecu_pnm/blob/main/firmware/ecu/main.c}{main.c}:
	
	\begin{minted}[frame=lines,framesep=2mm,fontsize=\normalsize,bgcolor=LightGray]{c}
int main(void) {
	// Hardware Abstraction Layer initialization
	halInit();
	
	// RTOS scheduler initialization
	chSysInit();
	
	// EEPROM initialization
	ecu_MEM_Init(); 
	
	// I/O Pins initialization
	ecu_GPIO_Init();
	
	// Serial Shell initialization
	ecu_SHELL_Init();
	
	// Input Capture initialization
	ecu_ICU_Init();
	
	// Analog-Digital initialization
	ecu_ADC_Init();
	
	// Generic Timer initialization
	ecu_GPT_Init();
	
	while (true) {
		// Serial Shell Loop initialization
		ecu_SHELL_Loop();
		
		// Latency to keep scheduling from race
		chThdSleepMilliseconds(500);
	}
}
	\end{minted}
	
	\section{Recommended Wiring Diagram}
	
	\includepdf[pages=-,angle=0]{images/wiring.pdf}
	
	\section{Interface Preview}
	
	In summary:
	\begin{itemize}
		\item Communicate with ECU through serial data
		
		\item Can Display engine throttle percent and RPM value in real-time
		
		\item Designed to manage Injection and Ignition mappings based on TPS-RPM
		
		\item Written in C++ and Qt5, compatible with Windows and GNU/Linux operating system
	\end{itemize}

	\subsection{Preview}
	
	\centering
	\begin{figure} [h]
		\centering
		
		\caption{Serial Data Control}
	\end{figure}
	
	\begin{figure} [h]
		\centering
		
		\caption{Injection and Ignition Mapping}
	\end{figure}

	\newpage
	\begin{figure} [h]
		\centering
		
		\caption{TPS and RPM Dial Monitoring}
	\end{figure}
	
	\raggedright
	\section{Assembled Parts}
	
	List of Assembled Parts:
	\begin{itemize}
		\item Custom Minimum Engine Control Unit prototype PCB
		
		\item ST Nucleo64 board with STM32F103RBT6 chip
		
		\item Mini USB Cables
		
		\item Acrylic Cranktooth in 12-miss-1 and 24-miss-1
	\end{itemize}

	\begin{figure} [h]
		\centering
		
		\caption{Currently Assembled Parts}
	\end{figure}
\end{document}

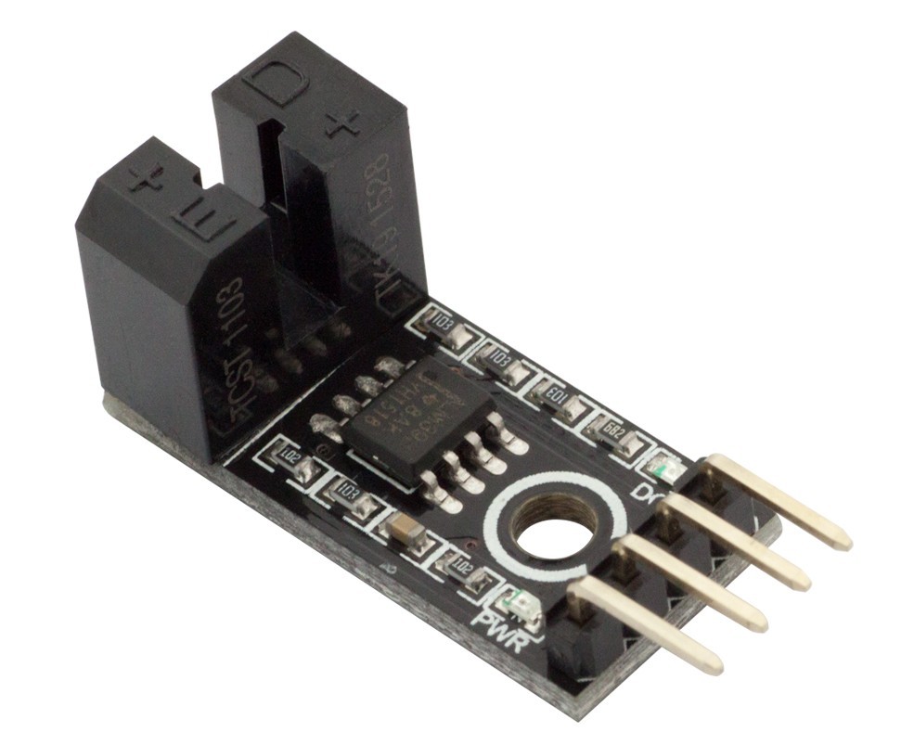
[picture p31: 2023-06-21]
docs/summaries/f103rb_nucleo/images/pulser.jpg

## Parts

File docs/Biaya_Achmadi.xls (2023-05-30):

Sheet: Akomodasi
Tanggal | Deskripsi | Nilai
20-05-2023 | Bis Surabaya | Rp 5000
20-05-2023 | Bis Restu | Rp 70000
20-05-2023 | Bis Restu | Rp 70000
20-05-2023 | Bis Surabaya | Rp 5000
Total |  | Rp 150000

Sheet: Parts
Deskripsi | Nilai
Akrilik Crankshaft Teeth | Rp 30000
Box Plastik | Rp 80000
Total | Rp 110000

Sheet: PCB ECU
Item | Price | Qty | Nilai | Toko/Kota | URL
STM32F1 Nucleo | Rp 600000 | 1 | Rp 600000 | Pinjam Achmadi | https://id.aliexpress.com/item/32837877993.html
IRF540 | Rp 14000 | 6 | Rp 84000 | Tokped Surabaya | https://www.tokopedia.com/wkh-elektronik/original-irf540-irf-540-irf540n-irf-540-n-transistor-mosfet
AMS117 5V | Rp 750 | 3 | Rp 2250 | Tokped Surabaya | https://www.tokopedia.com/mulsanne/ic-ams1117-5-volt-step-down-smd-800ma
FT232RL | Rp 60000 | 2 | Rp 120000 | Digiware Surabaya | https://digiwarestore.com/id/serial-communication/ft232rl-166019.html
Soket MiniUSB | Rp 5000 | 3 | Rp 15000 | Digiware Surabaya | https://digiwarestore.com/id/socket/socket-mini-usb-smt-312044.html
H11L1 | Rp 10000 | 3 | Rp 30000 | Eltech Surabaya | https://www.tokopedia.com/eltech-online/h11l1-h-11l1-h11-l1-optocoupler
2N3904 | Rp 1000 | 3 | Rp 3000 | Eltech Surabaya | https://www.tokopedia.com/eltech-online/2n3904-2n-3904-transistor-npn-to-92
4N35 | Rp 5000 | 6 | Rp 30000 | Eltech Surabaya | https://www.tokopedia.com/eltech-online/4n35-4n-35-general-purpose-6-pin-phototransistor-4n35-putih
LED Yellow 1206 | Rp 1000 | 3 | Rp 3000 | Digiware Surabaya | https://digiwarestore.com/id/led/led-yellow-super-bright-smd1206-c1632vyc-255025.html
LED Green 1206 | Rp 1000 | 3 | Rp 3000 | Digiware Surabaya | https://digiwarestore.com/id/led/led-green-super-bright-smd1206-255026.html
Terminal Screw | Rp 2000 | 8 | Rp 16000 | Tokped Surabaya | https://www.tokopedia.com/isee/terminal-block-kf-350-green-hijau-kf350-3pin-3p-screw-3-5mm-pcb-3-pin
Diode 1N4007 | Rp 500 | 2 | Rp 1000 | Tokped Surabaya | https://www.tokopedia.com/mri/dioda-in4007-1n-4007-in-4007-dip-diode-1n4007
OptoInteruptor | Rp 50000 | 2 | Rp 100000 | Tokped Surabaya | https://www.tokopedia.com/mogoz/diskon-fc-03-ir-infrared-kecepatan-po-opto-interruptor
Resistor 1206 | Rp 50000 | - | Rp 50000 | Gelondongan | -
Capacitor 1206 | Rp 50000 | - | Rp 50000 | Gelondongan | -
Cetak PCB Paketan | Rp 500000 | - | Rp 500000 | Raftech Bandung | https://www.tokopedia.com/raftech/jasa-cetak-pcb-general
Wirings | Rp 200000 | - | Rp 200000
Ongkir Online Shop | Rp 200000 | - | Rp 200000 | - | -
Akomodasi Belanja | Rp 200000 | - | Rp 200000 | - | -
Jasa Soldering | Rp 200000 | - | Rp 200000 | - | -
Total |  |  | Rp 2407250

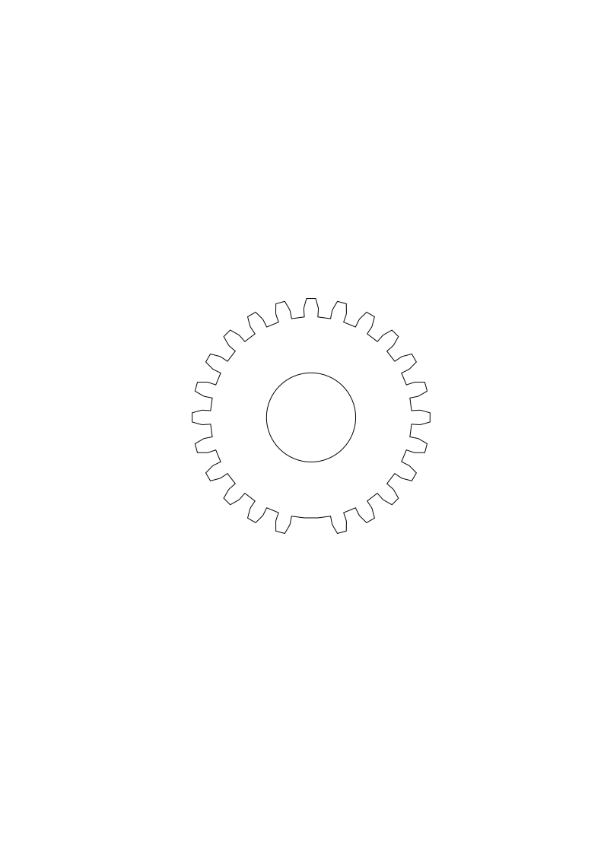
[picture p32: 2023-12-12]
parts/cranktooth/24m1/crankteeth_v2_plain.png

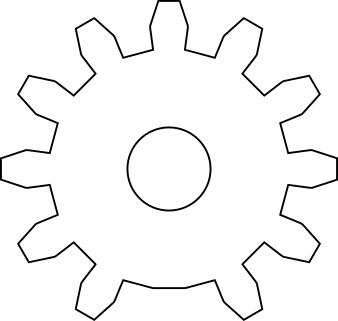
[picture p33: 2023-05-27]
parts/cranktooth/12m1/crankteeth_v0.png

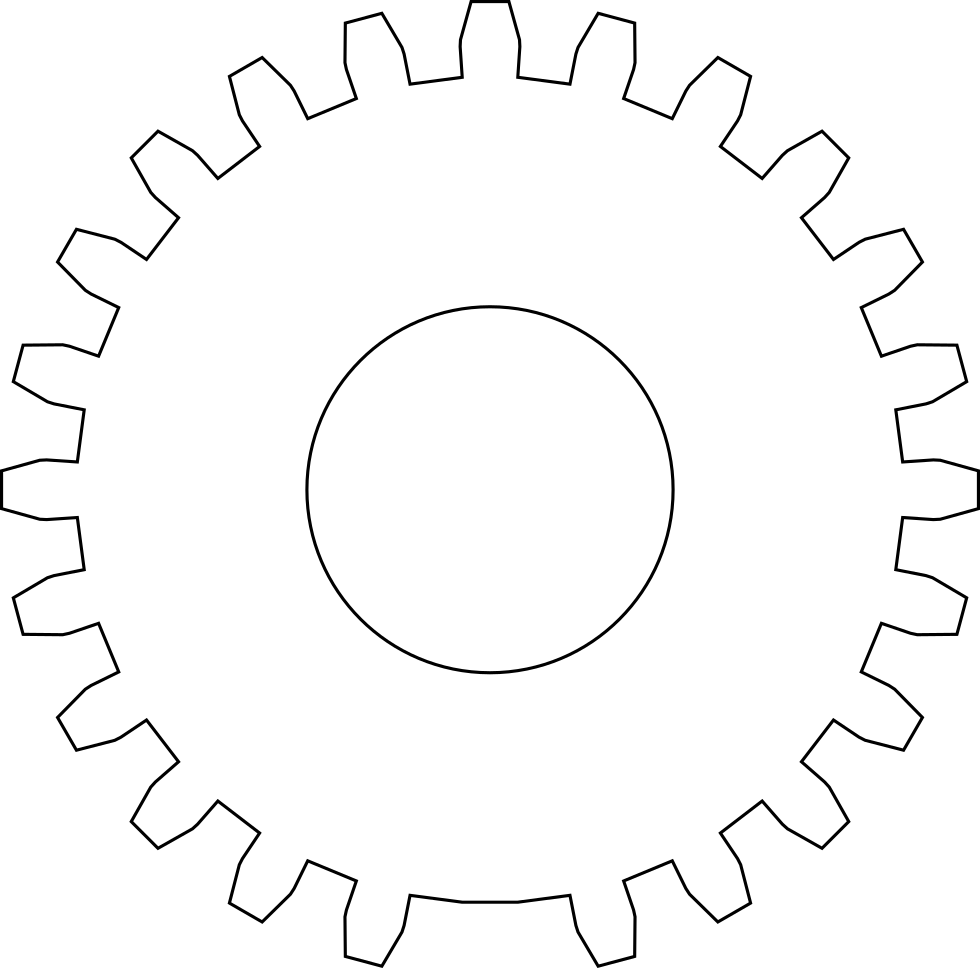
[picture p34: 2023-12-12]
parts/cranktooth/24m1/crankteeth_v2.png

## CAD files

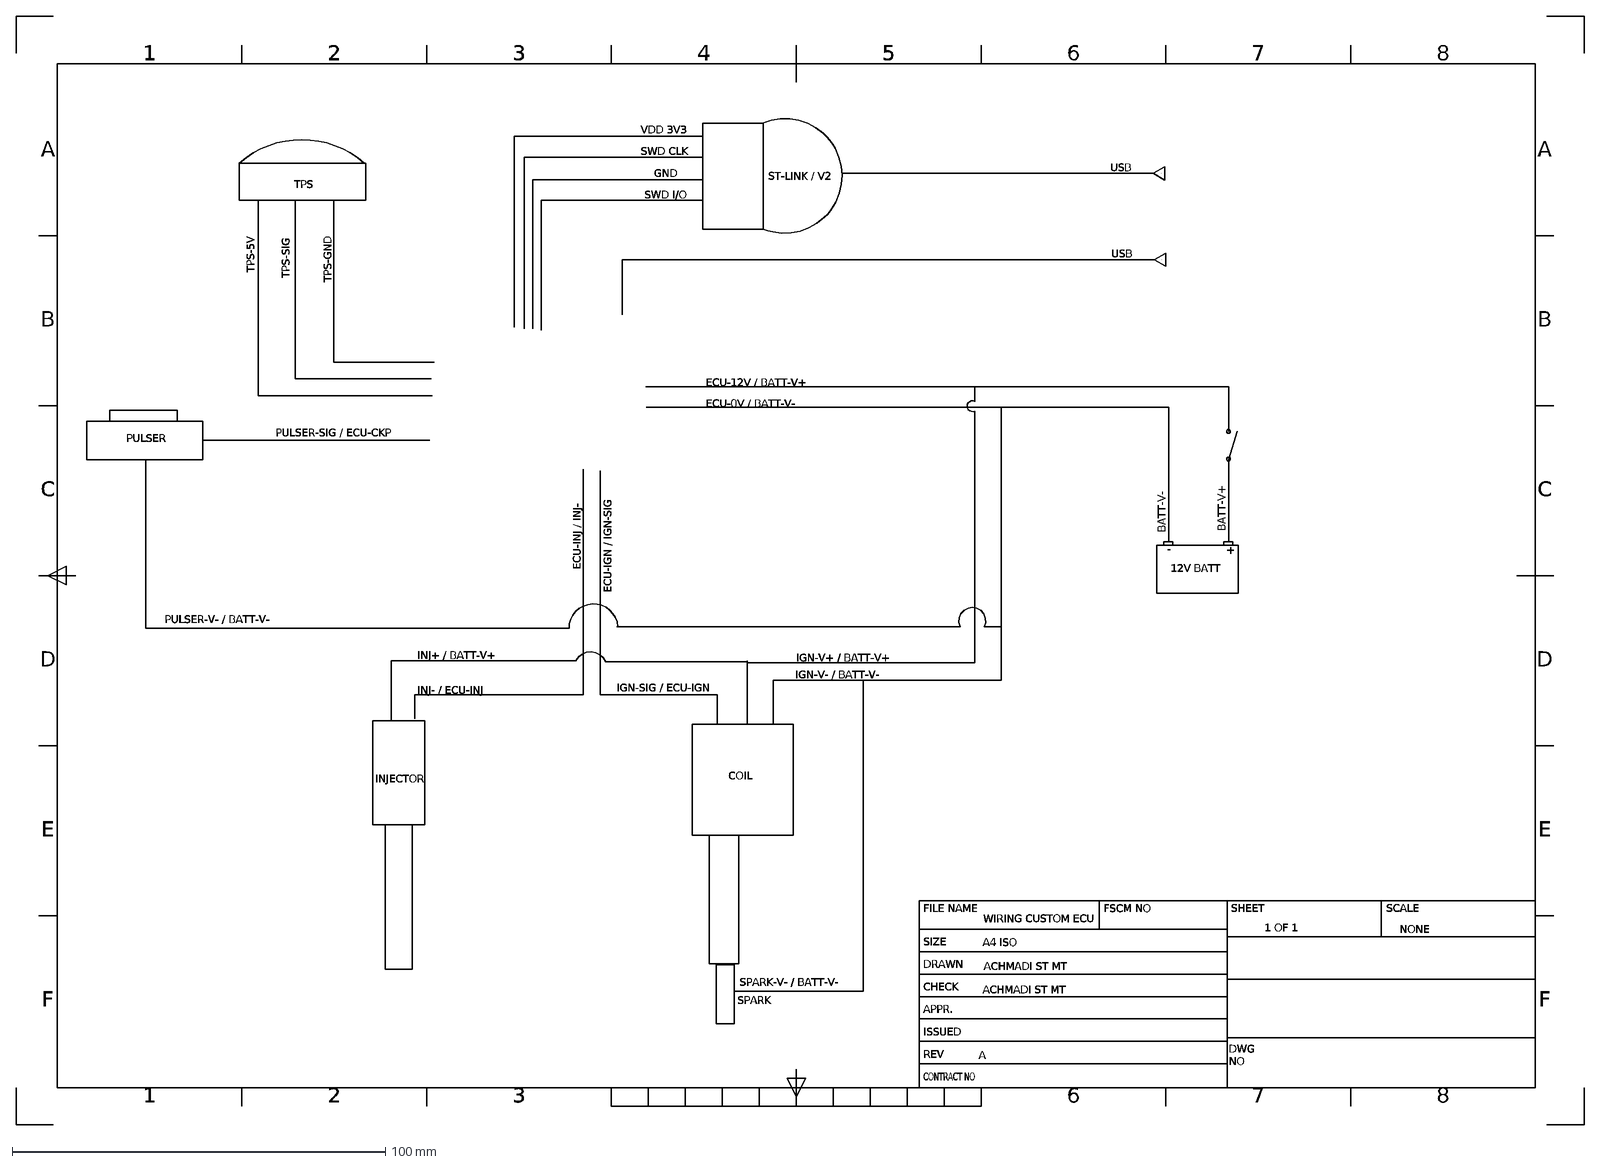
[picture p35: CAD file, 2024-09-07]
circuits/ecupnm_f051r8/Wiring.dxf
F
1
E
D
3
2
C
B
A
4
7
6
8
5
FSCM NO
SIZE
REV
CONTRACT NO
APPR.
ISSUED
CHECK
DRAWN
FILE NAME
SCALE
SHEET
DWG NO
INJ- / ECU-INJ
ECU-INJ / INJ-
ECU-12V / BATT-V+
ECU-0V / BATT-V-
12V BATT
+
-
SPARK
IGN-SIG / ECU-IGN
ECU-IGN / IGN-SIG
INJECTOR
COIL
INJ+ / BATT-V+
IGN-V+ / BATT-V+
IGN-V- / BATT-V-
BATT-V-
BATT-V+
PULSER-SIG / ECU-CKP
SPARK-V- / BATT-V-
TPS
TPS-5V
TPS-SIG
TPS-GND
PULSER
ST-LINK / V2
VDD 3V3
SWD CLK
GND
SWD I/O
USB
PULSER-V- / BATT-V-
WIRING CUSTOM ECU
A4 ISO
ACHMADI ST MT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

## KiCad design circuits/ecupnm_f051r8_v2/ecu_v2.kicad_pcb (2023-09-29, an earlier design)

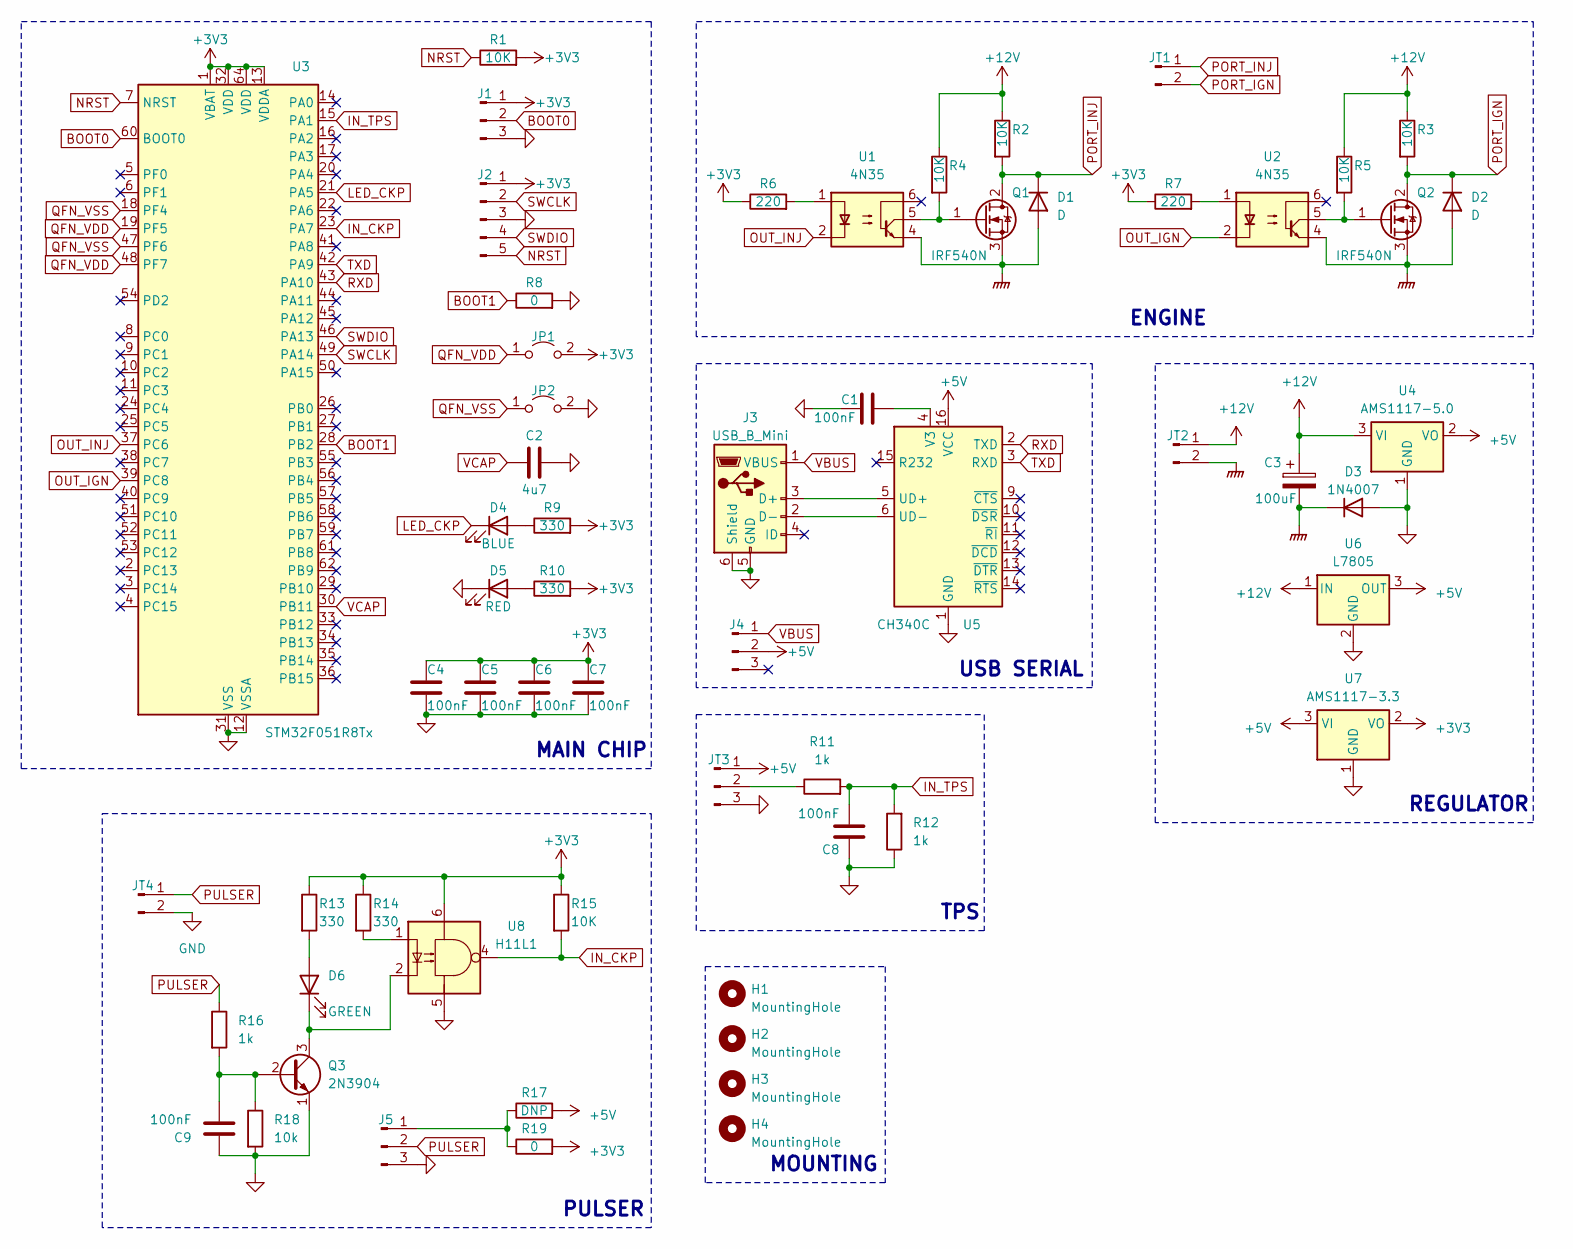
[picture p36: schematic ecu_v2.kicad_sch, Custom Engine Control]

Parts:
C1, C4, C5, C6, C7, C8, C9: 100nF; C_0805_2012Metric_Pad1.18x1.45mm_HandSolder
C2: 4u7; C_0805_2012Metric_Pad1.18x1.45mm_HandSolder
C3: 100uF; CP_Radial_D4.0mm_P2.00mm
D1, D2: D; D_DO-15_P10.16mm_Horizontal
D3: 1N4007; D_DO-41_SOD81_P10.16mm_Horizontal
D4: BLUE; LED_0805_2012Metric_Pad1.15x1.40mm_HandSolder
D5: RED; LED_0805_2012Metric_Pad1.15x1.40mm_HandSolder
D6: GREEN; LED_0805_2012Metric_Pad1.15x1.40mm_HandSolder
H1, H2, H3, H4: MountingHole; MountingHole_2.2mm_M2
J1, J4, J5: Conn_01x03_Pin; PinHeader_1x03_P2.54mm_Vertical
J2: Conn_01x05_Pin; PinHeader_1x05_P2.54mm_Vertical
J3: USB_B_Mini; USB_Mini-B_Wuerth_65100516121_Horizontal
JP1, JP2: Jumper_2_Open; SolderJumper-2_P1.3mm_Open_RoundedPad1.0x1.5mm
JT1, JT2, JT4: Conn_01x02_Pin; TerminalBlock_Altech_AK300-2_P5.00mm
JT3: Conn_01x03_Pin; TerminalBlock_Altech_AK300-3_P5.00mm
Q1, Q2: IRF540N; TO-220-3_Vertical
Q3: 2N3904; TO-92_Inline
R1, R2, R3, R4, R5, R15: 10K; R_0805_2012Metric_Pad1.20x1.40mm_HandSolder
R6, R7: 220; R_0805_2012Metric_Pad1.20x1.40mm_HandSolder
R8, R19: 0; R_0805_2012Metric_Pad1.20x1.40mm_HandSolder
R9, R10, R13, R14: 330; R_0805_2012Metric_Pad1.20x1.40mm_HandSolder
R11, R12, R16: 1k; R_0805_2012Metric_Pad1.20x1.40mm_HandSolder
R17: DNP; R_0805_2012Metric_Pad1.20x1.40mm_HandSolder
R18: 10k; R_0805_2012Metric_Pad1.20x1.40mm_HandSolder
U1, U2: 4N35; DIP-6_W7.62mm
U3: STM32F051R8Tx; LQFP-64_10x10mm_P0.5mm
U4: AMS1117-5.0; SOT-223-3_TabPin2
U5: CH340C; SOIC-16_3.9x9.9mm_P1.27mm
U6: L7805; TO-220-3_Vertical
U7: AMS1117-3.3; SOT-223-3_TabPin2
U8: H11L1; DIP-6_W7.62mm

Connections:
+3V3: C4.1, C5.1, C6.1, C7.1, J1.1, J2.1, JP1.2 (B), R1.2, R6.1, R7.1, R9.2, R10.2, R13.1, R14.1, R15.1, R19.2, U3.1 (VBAT), U3.13 (VDDA), U3.32 (VDD), U3.64 (VDD), U7.2 (VO), U8.6
+5V: J4.2, JT3.1, R17.2, U4.2 (VO), U5.16 (VCC), U6.3 (OUT), U7.3 (VI)
+12V: C3.1, JT2.1, R2.1, R3.1, R4.1, R5.1, U4.3 (VI), U6.1 (IN)
BOOT0: J1.2, U3.60 (BOOT0)
BOOT1: R8.1, U3.28 (PB2)
GND: C1.2, C2.2, C4.2, C5.2, C6.2, C7.2, C8.1, C9.1, D3.2 (A), D5.1 (K), J1.3, J2.3, J3.5 (GND), J3.6 (Shield), J5.3, JP2.2 (B), JT3.3, JT4.2, Q3.1 (E), R8.2, R12.1, R18.2, U3.12 (VSSA), U3.31 (VSS), U3.63 (VSS), U4.1 (GND), U5.1 (GND), U6.2 (GND), U7.1 (GND), U8.5
GNDPWR: C3.2, D1.2 (A), D2.2 (A), D3.1 (K), JT2.2, Q1.3 (S), Q2.3 (S), U1.4, U2.4
IN_CKP: R15.2, U3.23 (PA7), U8.4
IN_TPS: C8.2, R11.2, R12.2, U3.15 (PA1)
LED_CKP: D4.1 (K), U3.21 (PA5)
NRST: J2.5, R1.1, U3.7 (NRST)
unnamed: D4.2 (A), R9.1
unnamed: D5.2 (A), R10.1
unnamed: D6.2 (A), R13.2
unnamed: D6.1 (K), Q3.3 (C), U8.2
unnamed: J3.3 (D+), U5.5 (UD+)
unnamed: J3.2 (D-), U5.6 (UD-)
unnamed: J5.1, R17.1, R19.1
unnamed: JT3.2, R11.1
unnamed: Q1.1 (G), R4.2, U1.5
unnamed: Q2.1 (G), R5.2, U2.5
unnamed: C9.2, Q3.2 (B), R16.2, R18.1
unnamed: R6.2, U1.1
unnamed: R7.2, U2.1
unnamed: R14.2, U8.1
unnamed: C1.1, U5.4 (V3)
OUT_IGN: U2.2, U3.39 (PC8)
OUT_INJ: U1.2, U3.37 (PC6)
PORT_IGN: D2.1 (K), JT1.2, Q2.2 (D), R3.2
PORT_INJ: D1.1 (K), JT1.1, Q1.2 (D), R2.2
PULSER: J5.2, JT4.1, R16.1
QFN_VDD: JP1.1 (A), U3.19 (PF5), U3.48 (PF7)
QFN_VSS: JP2.1 (A), U3.18 (PF4), U3.47 (PF6)
RXD: U3.43 (PA10), U5.2 (TXD)
SWCLK: J2.2, U3.49 (PA14)
SWDIO: J2.4, U3.46 (PA13)
TXD: U3.42 (PA9), U5.3 (RXD)
VBUS: J3.1 (VBUS), J4.1
VCAP: C2.1, U3.30 (PB11)

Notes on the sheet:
REGULATOR
ENGINE
MAIN CHIP
TPS
PULSER
MOUNTING
USB SERIAL

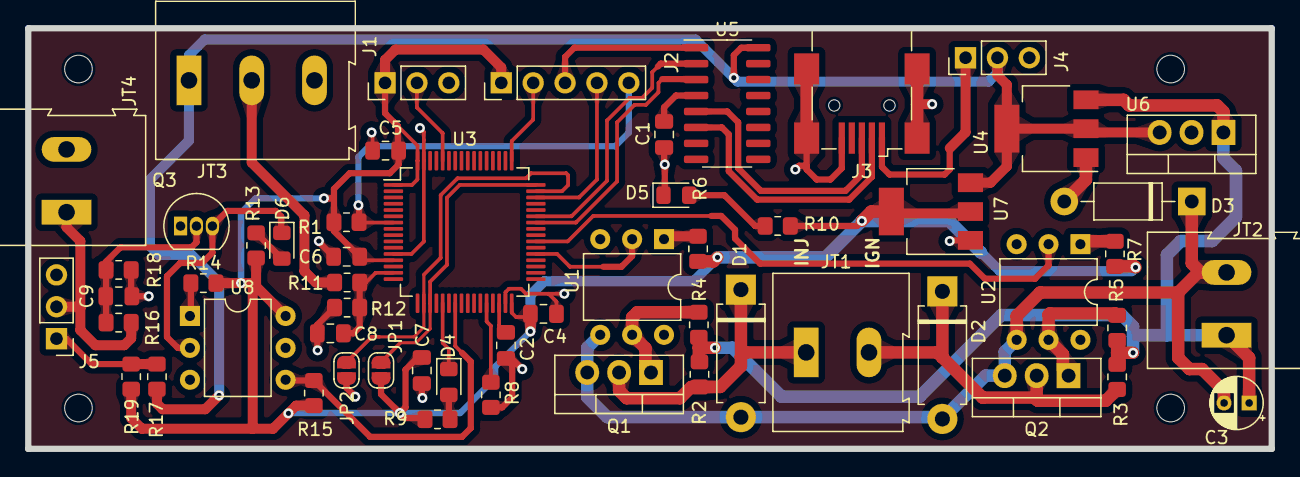
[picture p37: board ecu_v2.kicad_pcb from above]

Board: 2 copper layers, 99.1 x 33.5 mm, 60 parts (0 on the bottom side), 39 nets.

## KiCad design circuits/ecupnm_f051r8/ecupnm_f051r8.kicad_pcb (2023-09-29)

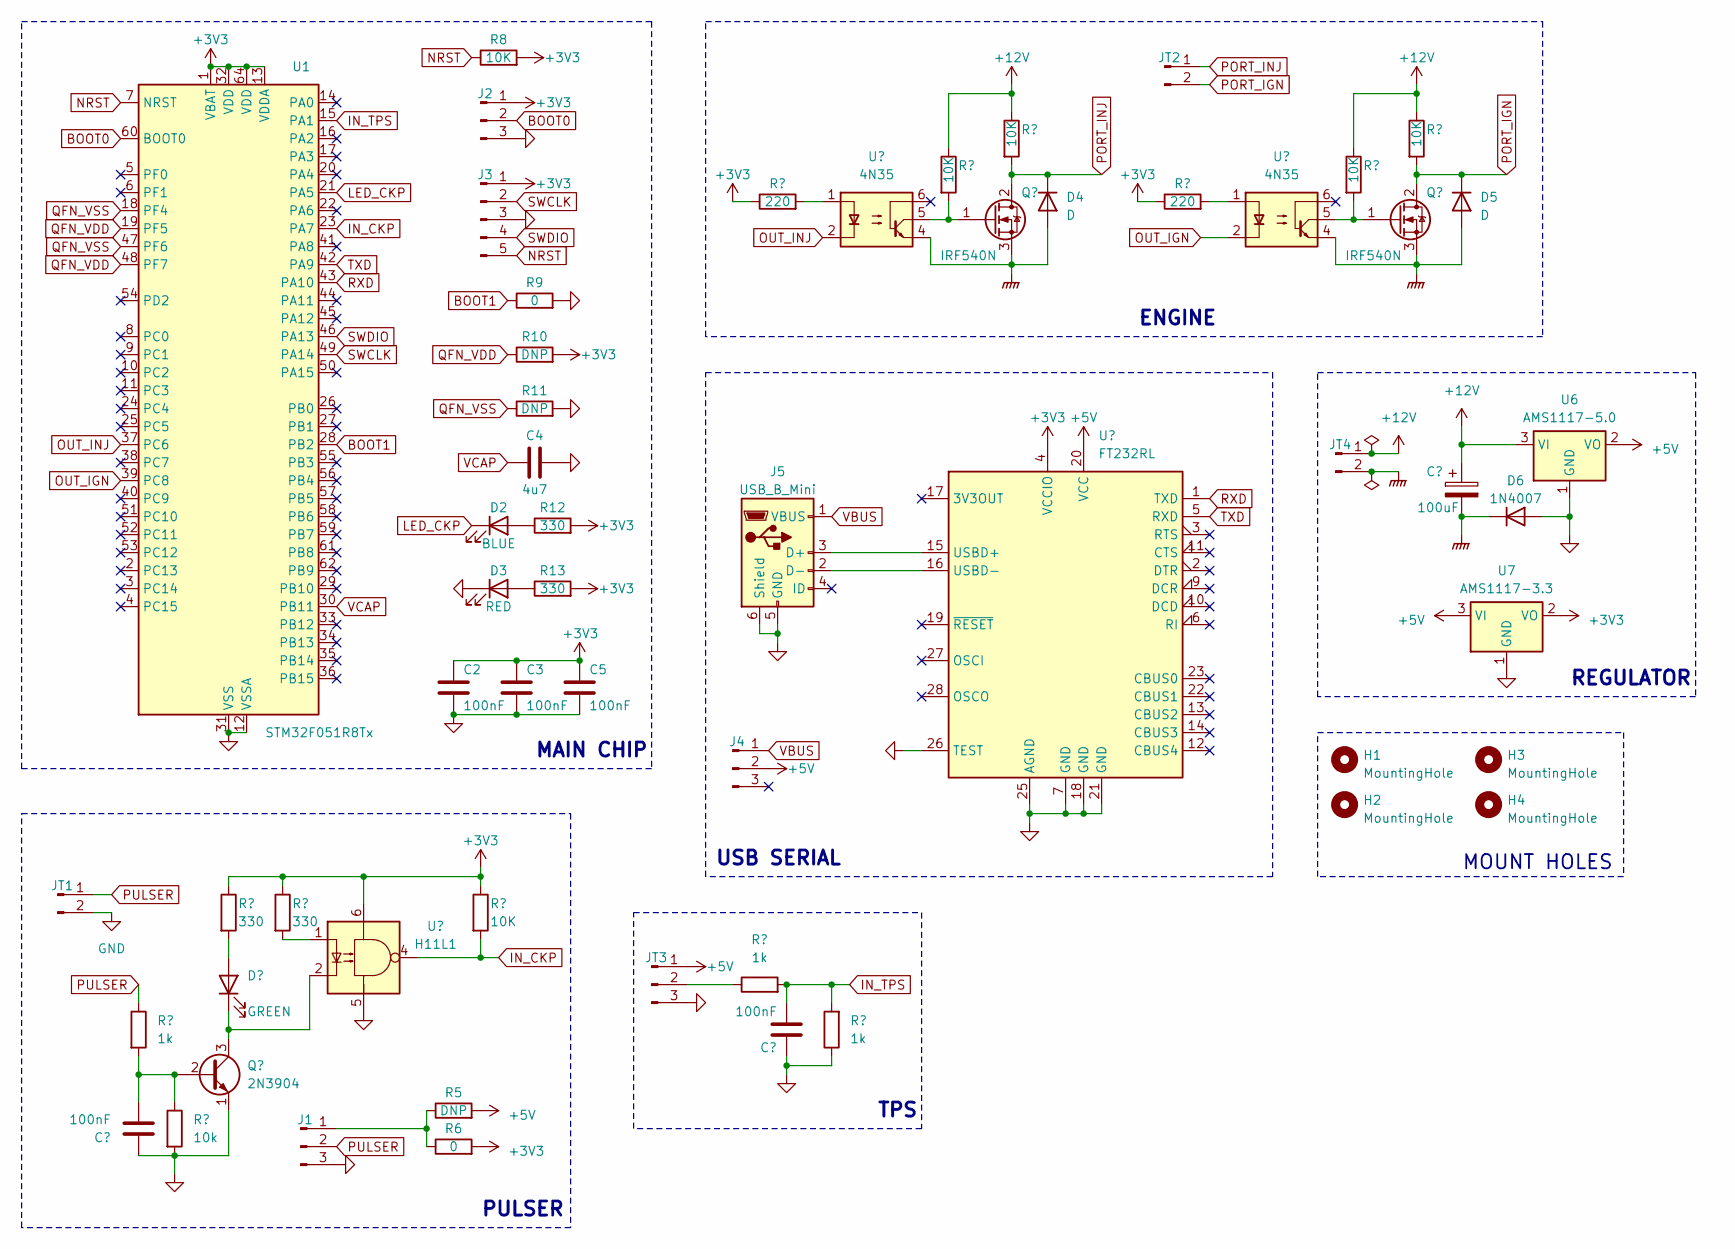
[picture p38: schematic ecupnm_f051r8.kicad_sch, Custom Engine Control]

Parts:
C1, C2, C3, C5, C6: 100nF; C_0805_2012Metric_Pad1.18x1.45mm_HandSolder
C4: 4u7; C_0805_2012Metric_Pad1.18x1.45mm_HandSolder
C7: 100uF; CP_Radial_D4.0mm_P2.00mm
D1: GREEN; LED_0805_2012Metric_Pad1.15x1.40mm_HandSolder
D2: BLUE; LED_0805_2012Metric_Pad1.15x1.40mm_HandSolder
D3: RED; LED_0805_2012Metric_Pad1.15x1.40mm_HandSolder
D4, D5: D; D_DO-15_P10.16mm_Horizontal
D6: 1N4007; D_DO-41_SOD81_P10.16mm_Horizontal
H1, H2, H3, H4: MountingHole; MountingHole_2.5mm
J1, J2, J4: Conn_01x03_Pin; PinHeader_1x03_P2.54mm_Vertical
J3: Conn_01x05_Pin; PinHeader_1x05_P2.54mm_Vertical
J5: USB_B_Mini; USB_Mini-B_Wuerth_65100516121_Horizontal
JT1, JT2, JT4: Conn_01x02_Pin; TerminalBlock_Altech_AK300-2_P5.00mm
JT3: Conn_01x03_Pin; TerminalBlock_Altech_AK300-3_P5.00mm
Q1: 2N3904; TO-92_Inline
Q2, Q3: IRF540N; TO-220-3_Vertical
R1, R20, R21: 1k; R_0805_2012Metric_Pad1.20x1.40mm_HandSolder
R2: 10k; R_0805_2012Metric_Pad1.20x1.40mm_HandSolder
R3, R4, R12, R13: 330; R_0805_2012Metric_Pad1.20x1.40mm_HandSolder
R5, R10, R11: DNP; R_0805_2012Metric_Pad1.20x1.40mm_HandSolder
R6, R9: 0; R_0805_2012Metric_Pad1.20x1.40mm_HandSolder
R7, R8, R15, R16, R18, R19: 10K; R_0805_2012Metric_Pad1.20x1.40mm_HandSolder
R14, R17: 220; R_0805_2012Metric_Pad1.20x1.40mm_HandSolder
U1: STM32F051R8Tx; LQFP-64_10x10mm_P0.5mm
U2: H11L1; DIP-6_W7.62mm
U3, U5: 4N35; DIP-6_W7.62mm
U4: FT232RL; SSOP-28_5.3x10.2mm_P0.65mm
U6: AMS1117-5.0; SOT-223-3_TabPin2
U7: AMS1117-3.3; SOT-223-3_TabPin2

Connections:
+3V3: C2.1, C3.1, C5.1, J2.1, J3.1, R3.1, R4.1, R6.2, R7.1, R8.2, R10.2, R12.2, R13.2, R14.1, R17.1, U1.1 (VBAT), U1.13 (VDDA), U1.32 (VDD), U1.64 (VDD), U2.6, U4.4 (VCCIO), U7.2 (VO)
+5V: J4.2, JT3.1, R5.2, U4.20 (VCC), U6.2 (VO), U7.3 (VI)
+12V: C7.1, JT4.1, R15.1, R16.1, R18.1, R19.1, U6.3 (VI)
BOOT0: J2.2, U1.60 (BOOT0)
BOOT1: R9.1, U1.28 (PB2)
GND: C1.1, C2.2, C3.2, C4.2, C5.2, C6.1, D3.1 (K), D6.2 (A), J1.3, J2.3, J3.3, J5.5 (GND), J5.6 (Shield), JT1.2, JT3.3, Q1.1 (E), R2.2, R9.2, R11.2, R21.1, U1.12 (VSSA), U1.31 (VSS), U1.63 (VSS), U2.5, U4.7 (GND), U4.18 (GND), U4.21 (GND), U4.25 (AGND), U4.26 (TEST), U6.1 (GND), U7.1 (GND)
GNDPWR: C7.2, D4.2 (A), D5.2 (A), D6.1 (K), JT4.2, Q2.3 (S), Q3.3 (S), U3.4, U5.4
IN_CKP: R7.2, U1.23 (PA7), U2.4
IN_TPS: C6.2, R20.2, R21.2, U1.15 (PA1)
LED_CKP: D2.1 (K), U1.21 (PA5)
NRST: J3.5, R8.1, U1.7 (NRST)
unnamed: D1.2 (A), R3.2
unnamed: D1.1 (K), Q1.3 (C), U2.2
unnamed: D2.2 (A), R12.1
unnamed: D3.2 (A), R13.1
unnamed: J1.1, R5.1, R6.1
unnamed: J5.3 (D+), U4.15 (USBD+)
unnamed: J5.2 (D-), U4.16 (USBD-)
unnamed: JT3.2, R20.1
unnamed: C1.2, Q1.2 (B), R1.2, R2.1
unnamed: Q2.1 (G), R15.2, U3.5
unnamed: Q3.1 (G), R18.2, U5.5
unnamed: R4.2, U2.1
unnamed: R14.2, U3.1
unnamed: R17.2, U5.1
OUT_IGN: U1.39 (PC8), U5.2
OUT_INJ: U1.37 (PC6), U3.2
PORT_IGN: D5.1 (K), JT2.2, Q3.2 (D), R19.2
PORT_INJ: D4.1 (K), JT2.1, Q2.2 (D), R16.2
PULSER: J1.2, JT1.1, R1.1
QFN_VDD: R10.1, U1.19 (PF5), U1.48 (PF7)
QFN_VSS: R11.1, U1.18 (PF4), U1.47 (PF6)
RXD: U1.43 (PA10), U4.1 (TXD)
SWCLK: J3.2, U1.49 (PA14)
SWDIO: J3.4, U1.46 (PA13)
TXD: U1.42 (PA9), U4.5 (RXD)
VBUS: J4.1, J5.1 (VBUS)
VCAP: C4.1, U1.30 (PB11)

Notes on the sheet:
TPS
MOUNT HOLES
REGULATOR
USB SERIAL
MAIN CHIP
PULSER
ENGINE

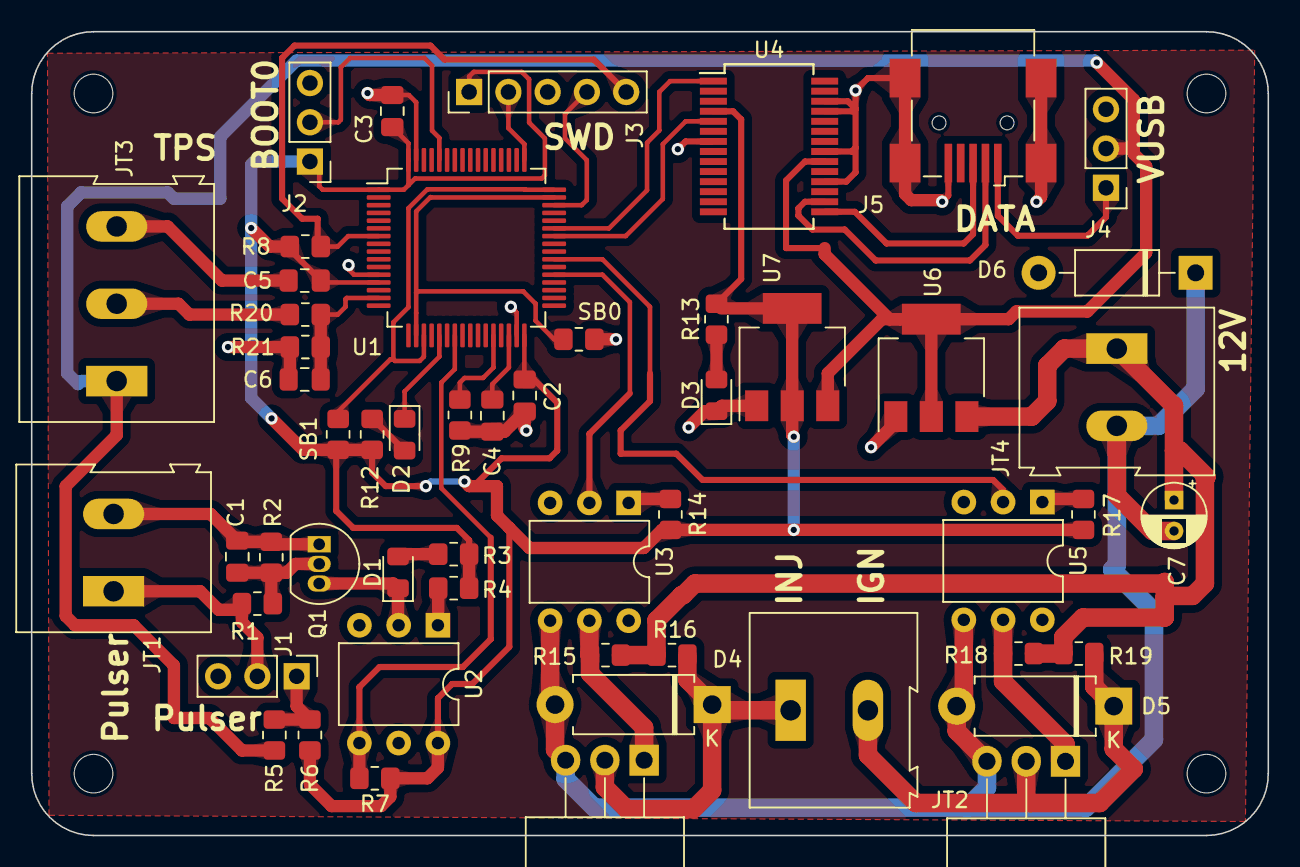
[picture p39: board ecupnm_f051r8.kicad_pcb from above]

Board: 2 copper layers, 80.0 x 52.0 mm, 57 parts (0 on the bottom side), 38 nets.

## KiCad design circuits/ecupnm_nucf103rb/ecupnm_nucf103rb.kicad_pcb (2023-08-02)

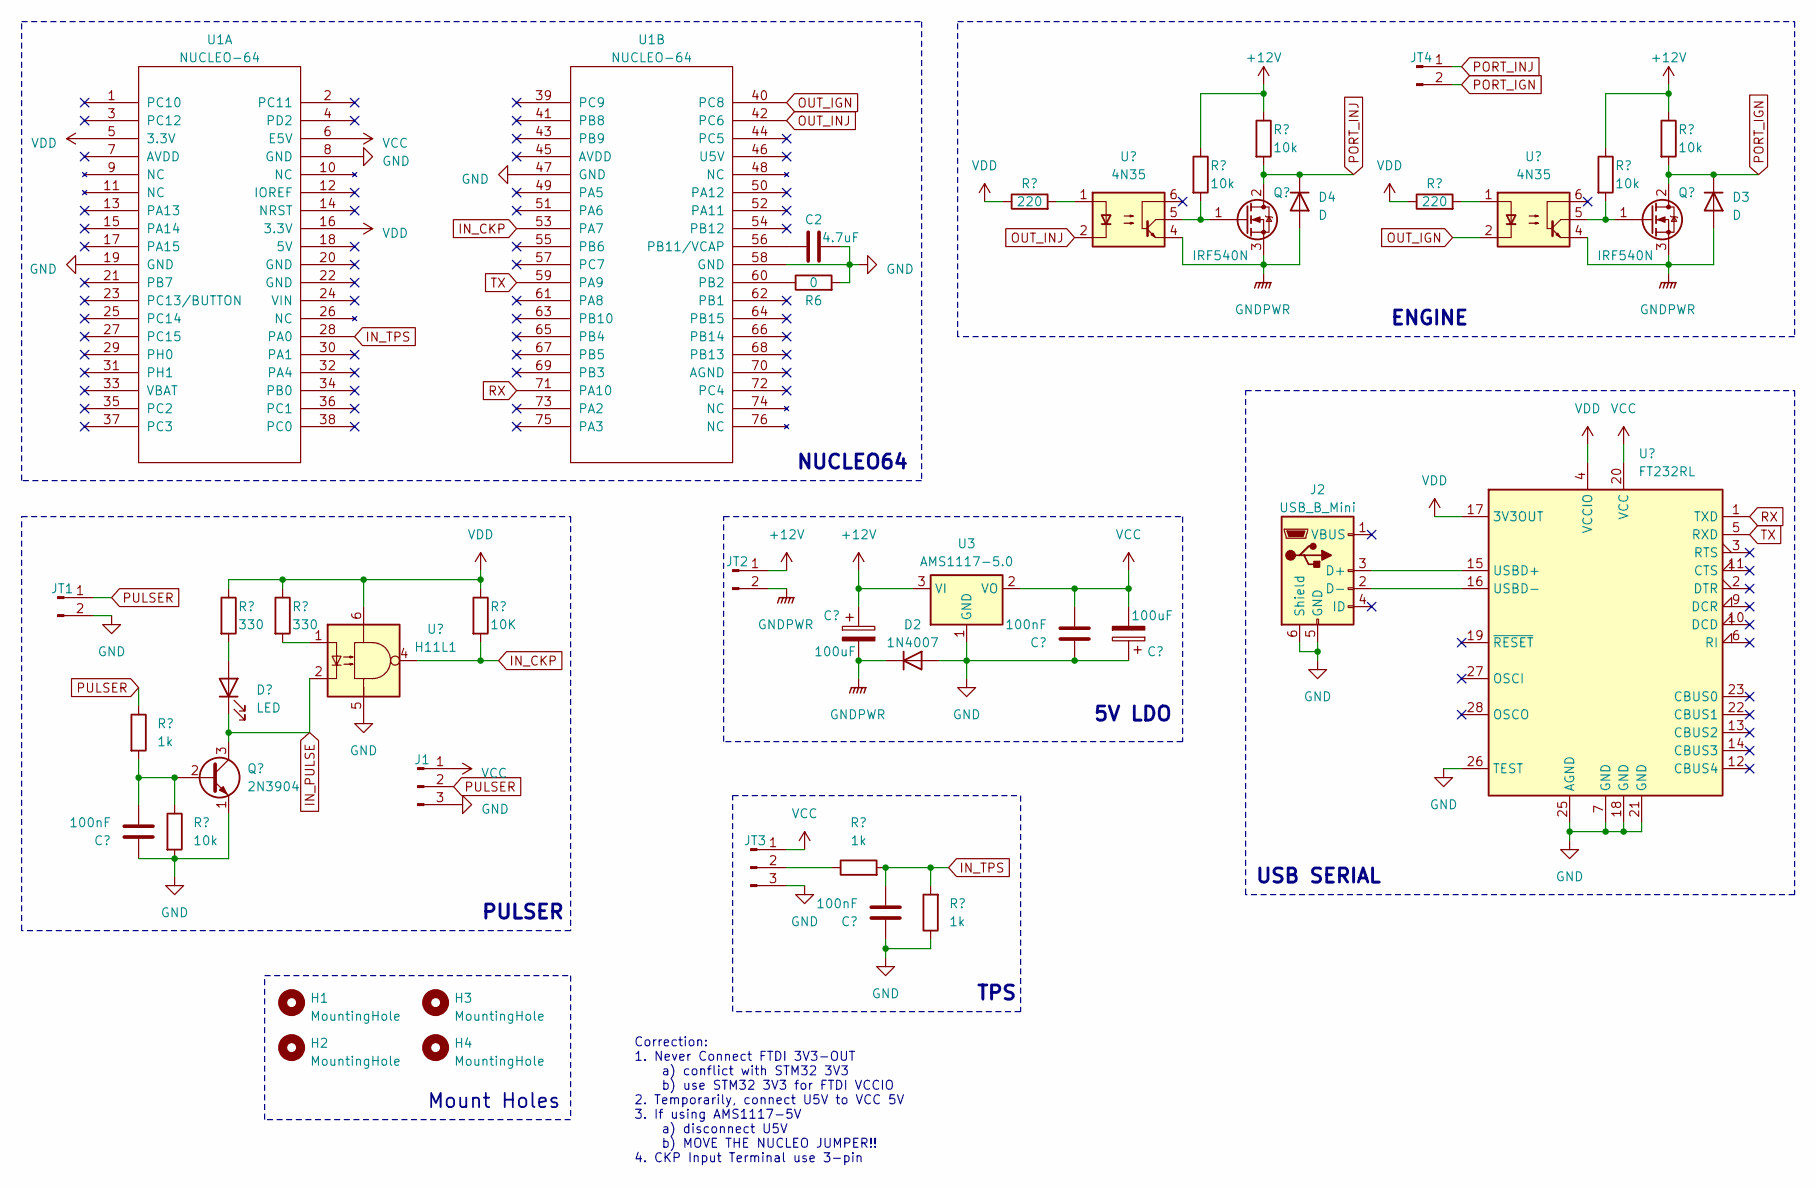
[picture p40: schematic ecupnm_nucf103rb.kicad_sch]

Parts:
C1, C4, C5: 100nF; C_1206_3216Metric_Pad1.33x1.80mm_HandSolder
C2: 4.7uF; C_1206_3216Metric_Pad1.33x1.80mm_HandSolder
C3, C6: 100uF; CP_Radial_D7.5mm_P2.50mm
D1: LED; LED_1206_3216Metric_Pad1.42x1.75mm_HandSolder
D2: 1N4007; D_DO-41_SOD81_P10.16mm_Horizontal
D3, D4: D; D_DO-15_P10.16mm_Horizontal
H1, H2, H3, H4: MountingHole; MountingHole_2.5mm
J1: Conn_01x03_Pin; PinHeader_1x03_P2.54mm_Vertical
J2: USB_B_Mini; USB_Mini-B_Wuerth_65100516121_Horizontal
JT1, JT2, JT4: Conn_01x02_Pin; TerminalBlock_Altech_AK300-2_P5.00mm
JT3: Conn_01x03_Pin; TerminalBlock_Altech_AK300-3_P5.00mm
Q1: 2N3904; TO-92_Inline
Q2, Q3: IRF540N; TO-220-3_Horizontal_TabDown
R1, R7, R8: 1k; R_1206_3216Metric_Pad1.30x1.75mm_HandSolder
R2, R10, R11, R13, R14: 10k; R_1206_3216Metric_Pad1.30x1.75mm_HandSolder
R3, R4: 330; R_1206_3216Metric_Pad1.30x1.75mm_HandSolder
R5: 10K; R_1206_3216Metric_Pad1.30x1.75mm_HandSolder
R6: 0; R_1206_3216Metric_Pad1.30x1.75mm_HandSolder
R9, R12: 220; R_1206_3216Metric_Pad1.30x1.75mm_HandSolder
U1: NUCLEO-64; Nucleo-64
U2: H11L1; DIP-6_W7.62mm
U3: AMS1117-5.0; SOT-223-3_TabPin2
U4, U5: 4N35; DIP-6_W7.62mm
U6: FT232RL; SSOP-28_5.3x10.2mm_P0.65mm

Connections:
+12V: C3.1, JT2.1, R10.1, R11.1, R13.1, R14.1, U3.3 (VI)
GND: C1.1, C2.2, C4.1, C5.1, C6.1, D2.2 (A), J1.3, J2.5 (GND), J2.6 (Shield), JT1.2, JT3.3, Q1.1 (E), R2.2, R6.2, R8.1, U1.8 (GND), U1.19 (GND), U1.47 (GND), U1.58 (GND), U2.5, U3.1 (GND), U6.7 (GND), U6.18 (GND), U6.21 (GND), U6.25 (AGND), U6.26 (TEST)
GNDPWR: C3.2, D2.1 (K), D3.2 (A), D4.2 (A), JT2.2, Q2.3 (S), Q3.3 (S), U4.4, U5.4
IN_CKP: R5.2, U1.53 (PA7), U2.4
IN_PULSE: D1.1 (K), Q1.3 (C), U2.2
IN_TPS: C4.2, R7.2, R8.2, U1.28 (PA0)
unnamed: D1.2 (A), R3.2
unnamed: J2.3 (D+), U6.15 (USBD+)
unnamed: J2.2 (D-), U6.16 (USBD-)
unnamed: JT3.2, R7.1
unnamed: C1.2, Q1.2 (B), R1.2, R2.1
unnamed: Q2.1 (G), R10.2, U4.5
unnamed: Q3.1 (G), R13.2, U5.5
unnamed: R4.2, U2.1
unnamed: R9.2, U4.1
unnamed: R12.2, U5.1
unnamed: R6.1, U1.60 (PB2)
unnamed: C2.1, U1.56 (PB11/VCAP)
OUT_IGN: U1.40 (PC8), U5.2
OUT_INJ: U1.42 (PC6), U4.2
PORT_IGN: D3.1 (K), JT4.2, Q3.2 (D), R14.2
PORT_INJ: D4.1 (K), JT4.1, Q2.2 (D), R11.2
PULSER: J1.2, JT1.1, R1.1
RX: U1.71 (PA10), U6.1 (TXD)
TX: U1.59 (PA9), U6.5 (RXD)
VCC: C5.2, C6.2, J1.1, JT3.1, U1.6 (E5V), U3.2 (VO), U6.20 (VCC)
VDD: R3.1, R4.1, R5.1, R9.1, R12.1, U1.5 (3.3V), U1.16 (3.3V), U2.6, U6.4 (VCCIO), U6.17 (3V3OUT)

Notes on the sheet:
Mount Holes
NUCLEO64
TPS
5V LDO
USB SERIAL
PULSER
ENGINE
Correction: 1. Never Connect FTDI 3V3-OUT a) conflict with STM32 3V3 b) use STM32 3V3 for FTDI VCCIO 2. Temporarily, connect U5V to VCC 5V 3. If using AMS1117-5V a) disconnect U5V b) MOVE THE NUCLEO JUMPER!! 4. CKP Input Terminal use 3-pin

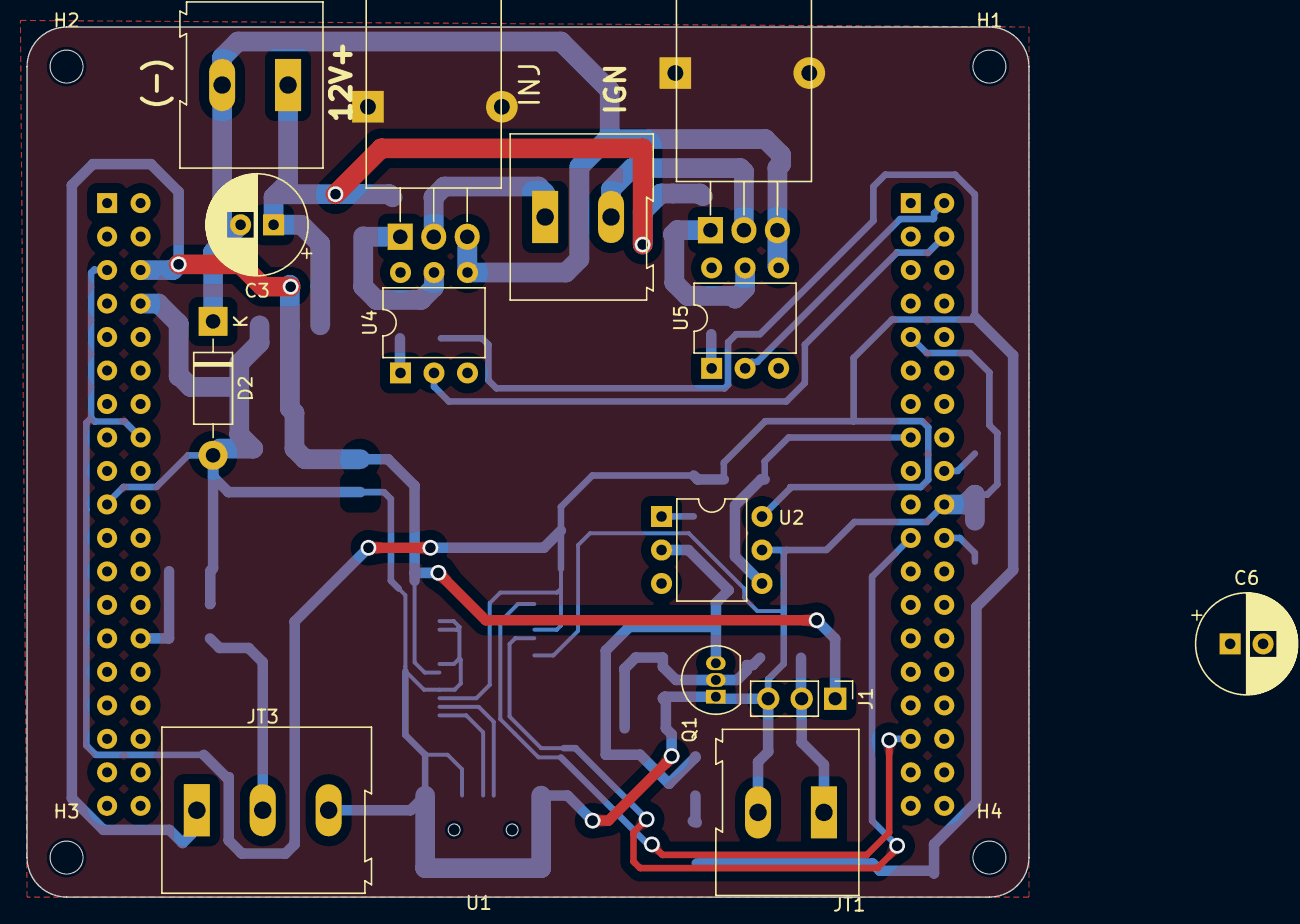
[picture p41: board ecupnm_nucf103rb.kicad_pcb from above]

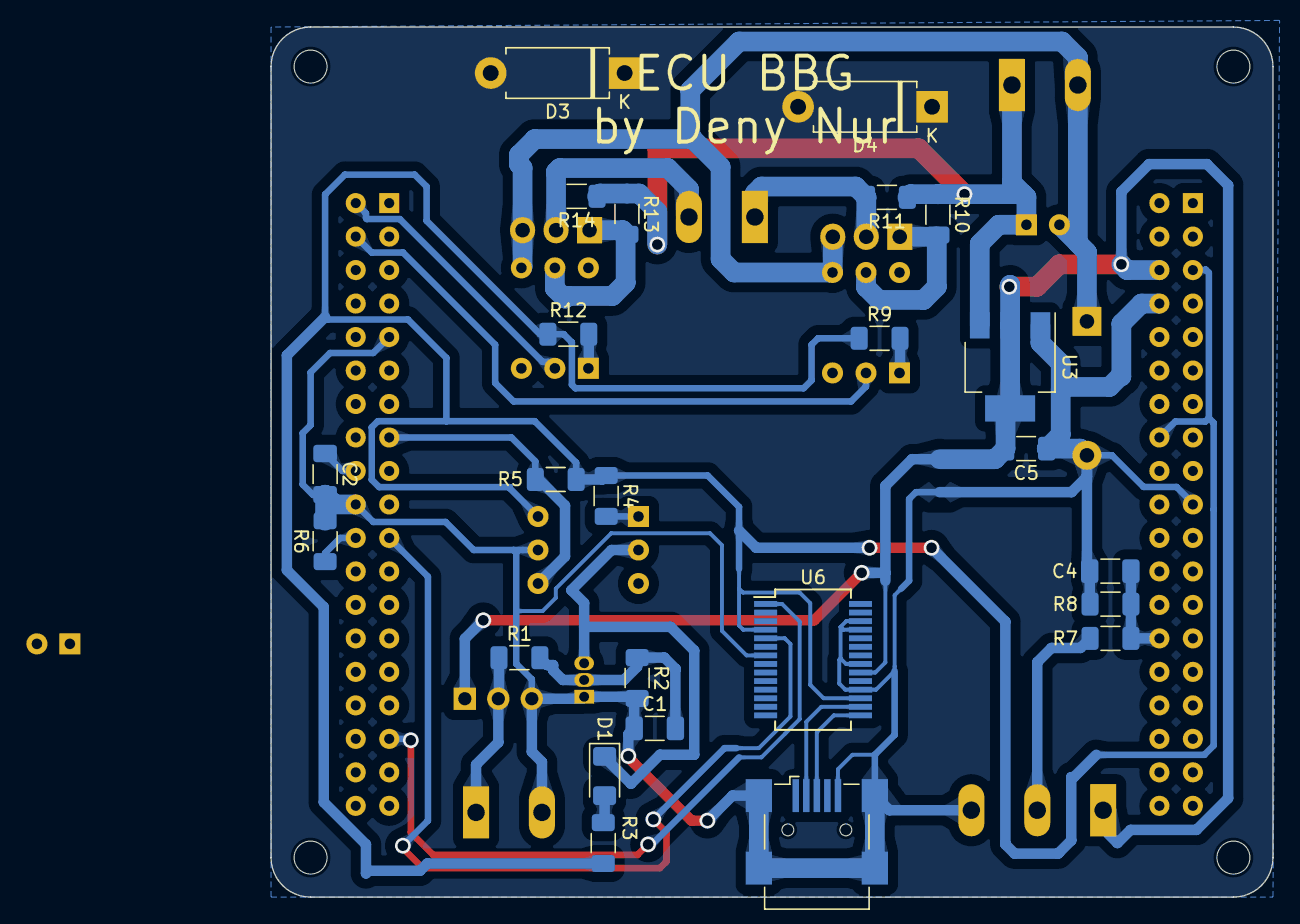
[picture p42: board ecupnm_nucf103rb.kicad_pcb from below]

Board: 2 copper layers, 76.0 x 66.0 mm, 43 parts (24 on the bottom side), 27 nets.

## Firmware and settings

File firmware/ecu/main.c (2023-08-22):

/**
 * @file main.c
 * @brief Main Entry Program
 *
 * @addtogroup MAIN
 * @{
 */

/*
    ChibiOS - Copyright (C) 2006..2018 Giovanni Di Sirio

    Licensed under the Apache License, Version 2.0 (the "License");
    you may not use this file except in compliance with the License.
    You may obtain a copy of the License at

        http://www.apache.org/licenses/LICENSE-2.0

    Unless required by applicable law or agreed to in writing, software
    distributed under the License is distributed on an "AS IS" BASIS,
    WITHOUT WARRANTIES OR CONDITIONS OF ANY KIND, either express or implied.
    See the License for the specific language governing permissions and
    limitations under the License.
*/

#include "ecu_config.h"
#include "ecu_includes.h"

/*
 * Application entry point.
 */
int main(void) {

	// Hardware Abstraction Layer initialization
	halInit();

	// RTOS scheduler initialization
	chSysInit();

	// EEPROM initialization
#if ECU_USE_MEM
	ecu_MEM_Init();
#endif

	// I/O Pins initialization
#if ECU_USE_GPIO
	ecu_GPIO_Init();
#endif

	// Serial Shell initialization
#if ECU_USE_SHELL
	ecu_SHELL_Init();
#endif

	// Input Capture initialization
#if ECU_USE_ICU
	ecu_ICU_Init();
#endif

	// Analog-Digital initialization
#if ECU_USE_ADC
	ecu_ADC_Init();
#endif

	// Generic Timer initialization
#if ECU_USE_GPT
	ecu_GPT_Init();
#endif

	while (true) {
		// Serial Shell Loop initialization
	#if ECU_USE_SHELL
		ecu_SHELL_Loop();
	#endif

		// Latency to keep scheduling from race
		chThdSleepMilliseconds(500);
	}
}

/**  @} */

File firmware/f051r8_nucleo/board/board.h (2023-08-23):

/*
    ChibiOS - Copyright (C) 2006..2015 Giovanni Di Sirio

    Licensed under the Apache License, Version 2.0 (the "License");
    you may not use this file except in compliance with the License.
    You may obtain a copy of the License at

        http://www.apache.org/licenses/LICENSE-2.0

    Unless required by applicable law or agreed to in writing, software
    distributed under the License is distributed on an "AS IS" BASIS,
    WITHOUT WARRANTIES OR CONDITIONS OF ANY KIND, either express or implied.
    See the License for the specific language governing permissions and
    limitations under the License.
*/

#ifndef _BOARD_H_
#define _BOARD_H_

/*
 * Setup for ST STM32F0-Discovery board.
 */

/*
 * Board identifier.
 */
#define BOARD_ST_STM32F0_DISCOVERY
#define BOARD_NAME                  "ST STM32F0-Discovery"

/*
 * Board oscillators-related settings.
 * NOTE: LSE not fitted.
 * NOTE: HSE not fitted.
 */
#if !defined(STM32_LSECLK)
#define STM32_LSECLK                0U
#endif

#define STM32_LSEDRV                (3U << 3U)

#if !defined(STM32_HSECLK)
#define STM32_HSECLK                0U
#endif

#define STM32_HSE_BYPASS

/*
 * MCU type as defined in the ST header.
 */
#define STM32F051x8

/*
 * IO pins assignments.
 */
#define GPIOA_BUTTON                0U
#define GPIOA_PIN1                  1U
#define GPIOA_PIN2                  2U
#define GPIOA_PIN3                  3U
#define GPIOA_PIN4                  4U
#define GPIOA_PIN5                  5U
#define GPIOA_PIN6                  6U
#define GPIOA_PIN7                  7U
#define GPIOA_PIN8                  8U
#define GPIOA_PIN9                  9U
#define GPIOA_PIN10                 10U
#define GPIOA_PIN11                 11U
#define GPIOA_PIN12                 12U
#define GPIOA_SWDAT                 13U
#define GPIOA_SWCLK                 14U
#define GPIOA_PIN15                 15U

#define GPIOB_PIN0                  0U
#define GPIOB_PIN1                  1U
#define GPIOB_PIN2                  2U
#define GPIOB_PIN3                  3U
#define GPIOB_PIN4                  4U
#define GPIOB_PIN5                  5U
#define GPIOB_PIN6                  6U
#define GPIOB_PIN7                  7U
#define GPIOB_PIN8                  8U
#define GPIOB_PIN9                  9U
#define GPIOB_PIN10                 10U
#define GPIOB_PIN11                 11U
#define GPIOB_PIN12                 12U
#define GPIOB_PIN13                 13U
#define GPIOB_PIN14                 14U
#define GPIOB_PIN15                 15U

#define GPIOC_PIN0                  0U
#define GPIOC_PIN1                  1U
#define GPIOC_PIN2                  2U
#define GPIOC_PIN3                  3U
#define GPIOC_PIN4                  4U
#define GPIOC_PIN5                  5U
#define GPIOC_PIN6                  6U
#define GPIOC_PIN7                  7U
#define GPIOC_LED4                  8U
#define GPIOC_LED3                  9U
#define GPIOC_PIN10                 10U
#define GPIOC_PIN11                 11U
#define GPIOC_PIN12                 12U
#define GPIOC_PIN13                 13U
#define GPIOC_OSC32_IN              14U
#define GPIOC_OSC32_OUT             15U

#define GPIOD_PIN0                  0U
#define GPIOD_PIN1                  1U
#define GPIOD_PIN2                  2U
#define GPIOD_PIN3                  3U
#define GPIOD_PIN4                  4U
#define GPIOD_PIN5                  5U
#define GPIOD_PIN6                  6U
#define GPIOD_PIN7                  7U
#define GPIOD_PIN8                  8U
#define GPIOD_PIN9                  9U
#define GPIOD_PIN10                 10U
#define GPIOD_PIN11                 11U
#define GPIOD_PIN12                 12U
#define GPIOD_PIN13                 13U
#define GPIOD_PIN14                 14U
#define GPIOD_PIN15                 15U

#define GPIOF_OSC_IN                0U
#define GPIOF_OSC_OUT               1U
#define GPIOF_PIN2                  2U
#define GPIOF_PIN3                  3U
#define GPIOF_PIN4                  4U
#define GPIOF_PIN5                  5U
#define GPIOF_PIN6                  6U
#define GPIOF_PIN7                  7U
#define GPIOF_PIN8                  8U
#define GPIOF_PIN9                  9U
#define GPIOF_PIN10                 10U
#define GPIOF_PIN11                 11U
#define GPIOF_PIN12                 12U
#define GPIOF_PIN13                 13U
#define GPIOF_PIN14                 14U
#define GPIOF_PIN15                 15U
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

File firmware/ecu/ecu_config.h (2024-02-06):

/**
 * @file ecu_config.h
 * @brief Global Configuration header
 *
 * @addtogroup MAIN
 * @{
 */

#ifndef _ECU_CONFIG_H_
#define _ECU_CONFIG_H_

#include "ch.h"
#include "hal.h"

#define assert_param(expr) ((void)0)

#define ECU_SIMULATE    TRUE

#define ECU_USE_GPIO    TRUE
#define ECU_USE_SHELL   TRUE
#define ECU_USE_ICU     TRUE
#define ECU_USE_MEM     TRUE
#define ECU_USE_ADC     TRUE
#define ECU_USE_GPT     FALSE

#define ECU_OVF_DELAY   100

#define ECU_SIM_DELAY   chThdSleepMilliseconds(5)  // fastest RPM it might can be
#define ECU_COIL_DELAY  chThdSleepMicroseconds(500) // coil charging max delay without EMF

#endif

/**  @} */

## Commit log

2023-05-27 Nucleo64 Schematic
    [ecupnm_nucf103rb.kicad_pcb, ecupnm_nucf103rb.kicad_sch]
2023-05-27 Alternative F051 Dual Cylinder
    [basic_f051r8.kicad_pcb, basic_f051r8.kicad_sch]
2023-05-27 Update PCB
    [ecupnm_nucf103rb.kicad_sch]
2023-05-27 Nucleo64 PCB
    [ecupnm_nucf103rb.kicad_sch]
2023-05-27 Nucleo 64
    [ecupnm_nucf103rb.kicad_sch]
2023-05-27 ECU Nucleo Based
    [ecupnm_nucf103rb.kicad_pcb, ecupnm_nucf103rb.kicad_sch]
2023-05-27 Nucleo Based
    [ecupnm_nucf103rb.kicad_pcb]
2023-05-29 RAB PCB Nucleo64 Shield
    [Biaya_Achmadi.xls]
2023-05-30 Update RAB
    [Biaya_Achmadi.xls]
2023-06-07 Ganti Orientasi PCB ECU
    [ecupnm_nucf103rb.kicad_pcb, ecupnm_nucf103rb.kicad_sch]
2023-06-07 Order PCB
    [ecupnm_nucf103rb.kicad_pcb]
2023-06-07 Ganti Ukuran Vias
    [ecupnm_nucf103rb.kicad_pcb]
2023-06-16 Serial OK
    [ecupnm_nucf103rb.kicad_sch]
2023-06-18 Test TPS
    [ecupnm_nucf103rb.kicad_sch]
2023-06-19 PCB Nucleo Notes
    [ecupnm_nucf103rb.kicad_pcb, ecupnm_nucf103rb.kicad_sch]
2023-06-21 Progress Document
    [ecupnm_nucf103rb.kicad_pcb]
2023-08-02 Update Hasil Tes
    [ecupnm_nucf103rb.kicad_pcb, ecupnm_nucf103rb.kicad_sch]
2023-08-03 Try Rework into F051RB
    [board.h, halconf.h, mcuconf.h]
2023-08-04 Foward Development to actual board
2023-08-04 New PCB on STM32F051R8
    [basic_f051r8.kicad_pcb, basic_f051r8.kicad_sch, ecupnm_f051r8.kicad_pcb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]
2023-08-04 New PCB
    [ecupnm_f051r8.kicad_pcb, ecupnm_f051r8.kicad_sch]
2023-08-04 PCB Baru
    [ecupnm_f051r8.kicad_pcb, ecupnm_f051r8.kicad_sch]
2023-08-06 Mulai Order
    [ecupnm_f051r8.kicad_pcb, ecupnm_f051r8.kicad_sch]
2023-08-22 Komprehensif Board Header for F0
2023-08-22 Basic System OK
    [ecupnm_f051r8.kicad_sch]
2023-08-23 Simplify Board Header
2023-08-23 F0 ADC Not Works
    [ecu_adc.c, ecu_icu.c]
2023-08-23 F0 ADC not work
    [ecu_adc.c]
2023-08-23 F0 ADC Not Working
    [ecu_adc.c]
2023-08-24 ADC Wrong Pin
2023-09-11 Dokumen Catatan
    [ecupnm_f051r8.kicad_pcb]
2023-09-27 ECU V2
    [ecu_v2.kicad_pcb, ecu_v2.kicad_sch]
2023-09-29 New ECU PCB
    [ecu_v2.kicad_pcb]
2023-09-29 Update New PCB
    [ecu_v2.kicad_pcb, ecu_v2.kicad_sch]
2023-09-29 Update PCB New
    [ecu_v2.kicad_pcb]
2024-02-05 Short Charging is safe
    [ecu_config.h, ecu_engine.c, ecu_icu.c]
2024-02-05 Bugfixes and Engine Simulation
    [ecu_config.h, ecu_engine.c, ecu_icu.c]
2024-09-07 Tambah Wiring
    [Wiring.dxf]
2024-09-07 Wiring Drawing
    [Wiring.dxf]
